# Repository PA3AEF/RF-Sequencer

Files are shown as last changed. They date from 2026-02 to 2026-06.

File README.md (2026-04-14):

# **RF‑Sequencer**

The RF‑Sequencer provides deterministic, safe, and hardware‑independent control of RF transmit and receive path transitions.  
It is designed for radio systems that require strict sequencing, amplifier protection, and predictable relay behavior under all conditions.

The firmware architecture emphasizes clarity, safety, and long‑term maintainability.  
Relay hardware, timing rules, and protection logic are abstracted behind stable interfaces, ensuring consistent operation across diverse station configurations.
Earlier work, such as the concepts published by W1GHZ (Paul Wade) helped establish the fundamental principles of safe RF path control.
This RF‑Sequencer continues that lineage with a modern, firmware‑driven architecture that emphasizes clarity, determinism, and long‑term maintainability.

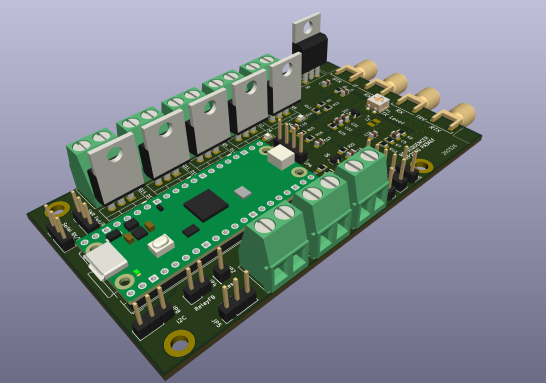
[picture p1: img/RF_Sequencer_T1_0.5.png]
RF Sequencer


## **Key Features**

- Deterministic transmit/receive sequencing  
- Integrated protection engine with SAFE‑mode enforcement  
- High‑speed ADC sampling for forward and reflected power  
- VSWR and fast reflected‑spike protection (REF_FAST)
- Hardware‑independent relay abstraction  
- Support for monostable and latching relays  
- Configurable timing and topology  
- Structured event output for external integration  
- Minimal configuration surface  
- Designed for reliability in demanding RF environments  

## **Why Another Sequencer?**

Existing RF sequencers, including the influential **W1GHZ Mark 5**, proved that microcontroller‑based protection can outperform analog timing chains. But modern stations demand more: deterministic firmware behavior, structured telemetry, remote monitoring, fault latching, and safe operation in unattended or tower‑top installations.

This project was created to provide:

- A **fully deterministic** main‑loop architecture  
- **Sub‑millisecond protection paths** (REF_FAST)  
- A **machine‑readable event stream** for dashboards and automation  
- A **human‑readable logging channel** for operators  
- A **calibration system** that adapts to any coupler  
- A **robust SAFE‑mode model** suitable for remote sites  

In short: it’s a **next‑generation MCU sequencer**, built on the ideas that came before but engineered for today’s RF environments.

## **Documentation**

The documentation is organized into several focused areas:

### **Overview**
High‑level conceptual introduction to the system.  
- `docs/overview/overview.md`

### **Architecture**
Detailed subsystem specifications and internal design.  
- `docs/architecture/firmware-architecture.md`  
- `docs/architecture/relay-architecture.md`

### **Integration**
External systems can interact with the sequencer through a structured event stream.  
Events reflect internal state transitions, protection triggers, relay actions, and measurement updates.   
Guidance for consuming sequencer events and coordinating external systems:
- `docs/integration/event-monitoring-example.md`
- `docs/integration/integration-examples.md`
- `docs/integration/integration-guide.md`

### **Quickstart**
Installation‑specific setup and basic configuration.  
- `docs/quickstart/quickstart.md`

### **Reference (optional)**
Command‑line reference, event definitions, and configuration schema.  
- `docs/reference/`

## **Design Philosophy**

The RF‑Sequencer is built around several core principles:

- **Safety first** — protection logic overrides all other behavior  
- **Determinism** — no asynchronous state changes  
- **Hardware abstraction** — relay details are isolated behind stable interfaces  
- **Minimal configuration** — only essential structural parameters are exposed  
- **Predictability** — timing and transitions follow strict rules  

These principles ensure reliable operation in both simple and complex RF installations.

## **Contributing**

Contributions that improve clarity, safety, or maintainability are welcome.  
Please ensure that changes preserve the architectural principles described in the documentation.

# **License**

This project uses a dual‑license model:

- **Firmware:** binary‑only, see `LICENSE_FIRMWARE.md`
- **Hardware:** CERN OHL‑P, see `LICENSE_HARDWARE.md`

A human‑readable summary is provided in:

- `LICENSE_NOTICE.md`

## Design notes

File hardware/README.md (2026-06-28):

# Hardware

Everything rekated to Hardware.  PCB's (4 layers!) can be easily ordered from JLCPCB. Submit the production ZIP file located in the PCB section. Files are provided for PCBA (PCB Assembly) but it is expensive for small series. Some experience with SMDsoldering is required.

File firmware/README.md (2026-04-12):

# **RF‑Sequencer Firmware**

This folder contains the **precompiled firmware binaries** for the RF‑Sequencer.  
The firmware is distributed as UF2 files and can be flashed directly to the microcontroller without installing any development tools.

If you only want to operate the sequencer, this is the only folder you need.

---

RF_Sequencer
## **Firmware Releases**

Precompiled firmware files are located in: firmware/releases

Each release contains:

- `RFSequencer-PicoTYPE-VX.Y.uf2` — main firmware image  
- `CHANGELOG.md` entry describing what changed  

You can also download firmware from the GitHub Releases page.

---

## **Flashing the Firmware**

The RF‑Sequencer uses a USB mass‑storage bootloader.  
To flash the firmware:

1. Connect the device to your computer via USB.
2. Enter bootloader mode:
   - Press and hold the BOOTSEL button  
   - Plug in the USB cable  
   - Release the button  
3. A new drive will appear (e.g., `RPI-RP2`).
4. Drag‑and‑drop the `.uf2` file onto the drive.
5. The device will reboot automatically.

Detailed instructions are available in: docs/quickstart/firmware-update.md

---

## **Configuration & Operation**

After flashing, connect to the device using any serial terminal:

- **115200 baud**
- **8N1**
- Local echo off

You will see the CLI prompt: >

Documentation for all commands is available in: docs/firmware/cli.md

---

## **Notes**

- Firmware source code is not included in this repository.
- All configuration values are stored in non‑volatile memory.
- You can safely update firmware without losing your settings.

---

If you need help updating or recovering the device, refer to the troubleshooting section:
`docs/troubleshooting/`

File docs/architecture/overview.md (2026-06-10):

---
title: Overview
parent: Architecture
nav_order: 1
---

# Overview

# **RF‑Sequencer Architecture Overview**

The RF‑Sequencer provides a deterministic control layer for managing RF path transitions, amplifier protection, and timing‑critical sequencing in radio systems.  
Its architecture is designed around clarity, predictability, and hardware independence, ensuring consistent behavior across a wide range of station configurations.

This document introduces the major architectural components and explains how they interact at a conceptual level.  
For detailed subsystem specifications, see:

- **Firmware Architecture**  
  `firmware-architecture.md`

- **Relay Subsystem Architecture**  
  `relay-architecture.md`

---

## **System Purpose**

The sequencer coordinates RF transmit and receive transitions while enforcing strict protection rules.  
Its primary goals are:

- ensuring safe amplifier operation  
- preventing hot‑switching of relays  
- providing deterministic timing behavior  
- abstracting hardware differences  
- enabling reliable integration with external systems  

The architecture is intentionally modular, allowing each subsystem to operate independently while contributing to a unified sequencing model.

---

## **Core Architectural Principles**

### **Determinism**
All timing, transitions, and protection responses follow predictable rules.  
No subsystem introduces nondeterministic behavior.

### **Hardware Abstraction**
Relay types, topologies, and station‑specific wiring are abstracted behind stable interfaces.  
The state machine and protection engine operate without knowledge of physical hardware details.

### **Safety First**
Faults, invalid states, and unexpected conditions always collapse into a known‑safe configuration.  
Protection logic is integrated throughout the architecture rather than layered on top.

### **Minimal Configuration Surface**
Only essential structural properties (relay topology, relay type, timing parameters) are configured.  
All other behavior is derived from architecture rules.

---

## **High‑Level Architecture**

The system is composed of several cooperating subsystems:

### **State Machine**
Defines the logical sequencing flow for transmit, receive, and SAFE transitions.  
It is the central coordinator of system behavior.  
See: `firmware-architecture.md`

### **Relay Subsystem**
Abstracts relay topology and actuation model, ensuring deterministic switching independent of hardware.  
See: `relay-architecture.md`

### **Protection Engine**
Monitors RF conditions, timing constraints, and system state to enforce safe operation.  
It can override the state machine to force SAFE transitions.

### **ADC and Measurement Layer**
Provides sampled measurements (e.g., forward/reflected power) used by the protection engine and calibration logic.

### **Event System**
Generates structured events for external systems, enabling integration with logging, GUIs, or automation.

### **Configuration Layer**
Stores structural and timing parameters that define installation‑specific behavior.

### **Main Execution Loop**
Executes the deterministic firmware cycle, evaluating state transitions, protection conditions, and relay actions.

---

## **Interaction Model**

The architecture is built around a clear flow of responsibility:

1. **Measurements** feed into  
2. **Protection logic**, which may override  
3. **State machine transitions**, which drive  
4. **Relay subsystem actions**, which define  
5. **The RF path**, while  
6. **Events** are emitted for external systems.

Each subsystem has a single, well‑defined role, minimizing coupling and simplifying long‑term maintenance.

---

## **Installation Variability**

The sequencer supports a wide range of RF station architectures, including:

- single‑relay TX‑only systems  
- dual‑relay TX+RX systems  
- monostable or latching relays  
- internal or external PA_RDY signaling  
- systems with or without external protection hardware  

These variations are expressed only through configuration and relay topology declarations.  
The architecture itself remains unchanged.

---

## **Design Objectives**

The architecture is designed to:

- provide a stable foundation for long‑term firmware evolution  
- support new relay types and station layouts without redesign  
- ensure predictable behavior under all conditions  
- minimize operator error through clear, deterministic rules  
- maintain separation between logical sequencing and physical hardware  

---

## **Further Reading**

For deeper architectural detail:

- **Firmware Architecture**  
  `firmware-architecture.md`

- **Relay Subsystem Architecture**  
  `relay-architecture.md`

For integration guidance:

- **Integration Examples**  
  `integration-examples.md`

---

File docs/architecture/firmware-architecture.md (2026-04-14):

# **Firmware Architecture**

The firmware architecture defines the deterministic execution model, subsystem boundaries, and interaction rules that govern all sequencing, protection, and relay behavior in the RF‑Sequencer.  
It is designed to provide predictable operation under all conditions while remaining independent of specific relay hardware, station topology, or external integration methods.

This document describes the internal architecture of the firmware.  
For a high‑level conceptual overview, see:

- `overview.md`

For a detailed description of the relay subsystem, see:

- `relay-architecture.md`

---

## **Architectural Goals**

The firmware is built around several core objectives:

- **Deterministic behavior**  
  Every transition, timing step, and protection response follows predictable rules.

- **Hardware abstraction**  
  Relay types, topologies, and electrical characteristics are hidden behind stable interfaces.

- **Safety under all conditions**  
  Faults, invalid states, and unexpected inputs always collapse into a known‑safe configuration.

- **Minimal configuration surface**  
  Only structural and timing parameters are configured; all other behavior is derived.

- **Long‑term maintainability**  
  Subsystems are isolated, with clear responsibilities and minimal coupling.

---

## **Execution Model**

The firmware operates in a deterministic main loop.  
Each cycle evaluates:

- state machine transitions  
- protection conditions  
- relay subsystem actions  
- event generation  
- timing progression  

No asynchronous execution paths modify system state.  
All changes occur within the controlled boundaries of the main loop, ensuring predictability and simplifying reasoning about system behavior.

---

## **State Machine**

The state machine defines the logical sequencing flow for transmit, receive, and SAFE transitions.  
It is the central coordinator of system behavior and the primary consumer of subsystem outputs.

The state machine:

- evaluates input conditions  
- determines the next logical state  
- requests relay transitions  
- coordinates timing windows  
- interacts with the protection engine  

The state machine does **not** interact with hardware directly.  
All physical actions are routed through the relay subsystem and timing model.

For relay subsystem details, see `relay-architecture.md`.

---

## **Relay Subsystem (Summary)**

The relay subsystem abstracts the physical RF switching hardware.  
It models:

- relay topology (single‑relay TX‑only or dual‑relay TX+RX)  
- actuation type (monostable or latching)  
- deterministic transition semantics  

The state machine issues logical relay requests; the subsystem translates them into hardware‑specific actions while guaranteeing:

- ordered transitions  
- bounded switching latency  
- no ambiguous intermediate states  
- consistent SAFE‑mode behavior  

For the full subsystem specification, see `relay-architecture.md`.

---

## **Protection Engine**

The protection engine enforces safe operation by monitoring measurement inputs, timing constraints, and system state.  
It can override the state machine to force SAFE transitions when required.

The protection engine evaluates:

- forward and reflected power  
- timing violations  
- invalid state combinations  
- external PA_RDY conditions  
- calibration validity  

When a protection condition is triggered, the engine:

- forces the system into SAFE mode  
- requests a known‑safe relay configuration  
- emits protection events  
- prevents further transitions until conditions clear  

Protection logic is integrated throughout the architecture rather than layered on top.

---

## **ADC and Measurement Layer**

The ADC subsystem provides sampled measurements used by the protection engine and calibration logic.  
It ensures:

- stable sampling intervals  
- noise‑aware averaging  
- predictable update timing  
- isolation from the main loop’s sequencing logic  

Measurements include:

- forward power  
- reflected power  
- auxiliary analog inputs (installation‑dependent)

The measurement layer does not interpret values; interpretation is handled by the protection engine and calibration subsystem.

---

## **Calibration Layer**

The calibration subsystem converts raw ADC readings into meaningful engineering values.  
It applies:

- scaling factors  
- offsets  
- linearization rules  

Calibration parameters are stored in the configuration layer and validated at startup.  
Invalid calibration data forces SAFE‑mode operation until corrected.

---

## **Event System**

The event system generates structured events that external systems can consume for logging, GUIs, or automation.  
Events are emitted for:

- state transitions  
- protection triggers  
- relay actions  
- configuration changes  
- measurement updates  

Events are strictly informational; they do not influence internal logic.

For integration examples, see `integration-examples.md`.

---

## **Configuration Layer**

The configuration layer stores installation‑specific parameters, including:

- relay topology  
- relay type  
- timing values  
- calibration data  
- protection thresholds  

Configuration is validated at startup.  
Invalid or incomplete configuration forces SAFE‑mode operation.

The configuration layer does not contain operational logic; it only provides structured data to other subsystems.

---

## **Main Execution Loop**

The main loop executes the deterministic firmware cycle:

1. read measurements  
2. evaluate protection conditions  
3. evaluate state machine transitions  
4. compute relay actions  
5. update timing windows  
6. emit events  

No subsystem modifies state outside this loop.  
This ensures predictable timing and simplifies debugging, integration, and long‑term maintenance.

---

## **Subsystem Boundaries**

Each subsystem has a single, well‑defined responsibility:

- **State Machine** — logical sequencing  
- **Relay Subsystem** — hardware abstraction  
- **Protection Engine** — safety enforcement  
- **ADC Layer** — measurement acquisition  
- **Calibration Layer** — measurement interpretation  
- **Event System** — external communication  
- **Configuration Layer** — installation parameters  
- **Main Loop** — deterministic execution  

This separation ensures that changes in one subsystem do not propagate unintended effects into others.

---

## **Design Rationale**

The architecture is intentionally conservative.  
RF systems demand predictable behavior, and the cost of nondeterminism is high.  
By isolating subsystems, enforcing strict sequencing rules, and abstracting hardware differences, the firmware remains stable across:

- new relay types  
- new station architectures  
- new protection requirements  
- future firmware extensions  

The architecture is designed to evolve without compromising safety or determinism.

---

## **Further Reading**

- **Architecture Overview**  
  `overview.md`

- **Relay Subsystem Architecture**  
  `relay-architecture.md`

- **Integration Examples**  
  `integration-examples.md`

---

**File 2 of 4 complete.**  
Say **“next”** and I will deliver **relay-architecture.md**.

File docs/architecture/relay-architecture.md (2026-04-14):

# **Relay Subsystem Architecture**

The relay subsystem provides the abstraction layer between the firmware’s logical sequencing model and the physical RF switching hardware.  
Its purpose is to ensure deterministic, safe, and hardware‑independent relay behavior across all supported station configurations.

This document describes the relay subsystem at an architectural level.  
For the full firmware architecture, see:

- `firmware-architecture.md`

For a high‑level conceptual overview, see:

- `overview.md`

---

## **Purpose and Scope**

The relay subsystem defines how the firmware models, controls, and validates RF switching hardware.  
It isolates the state machine and protection engine from:

- relay topology  
- relay actuation type  
- electrical characteristics  
- timing requirements  
- installation‑specific wiring  

By abstracting these details, the subsystem ensures consistent sequencing behavior regardless of the underlying hardware.

---

## **Topology Model**

The subsystem supports two structural relay configurations:

### **Single‑Relay (TX‑Only)**
A single switching element defines the RF path.  
This topology is used in simple installations where receive path switching is not required.

### **Dual‑Relay (TX+RX)**
Independent transmit and receive paths are controlled by separate relays.  
This topology supports more complex station architectures and provides full control over both RF paths.

Topology is a **structural property** of the installation.  
Once declared, all sequencing and SAFE‑mode behavior is derived automatically.

---

## **Actuation Model**

Relays are modeled using an abstract actuation interface that supports:

- **Monostable relays**  
  Require continuous drive to maintain state.

- **Latching relays**  
  Use pulse‑driven actuation and retain state without continuous power.

The firmware does not expose electrical characteristics to higher layers.  
The state machine interacts only with **logical relay states**, while the subsystem handles the required actuation behavior.

---

## **Deterministic Transition Semantics**

All relay transitions follow strict architectural rules:

- transitions occur in a defined order  
- switching latency is bounded  
- intermediate states are never exposed  
- SAFE‑mode transitions override all other requests  
- relay actions are synchronized with the main execution loop  

These guarantees ensure that the RF path is always in a well‑defined state, even during rapid transitions or fault conditions.

---

## **SAFE‑Mode Behavior**

The relay subsystem integrates tightly with the protection engine.  
When a protection condition is triggered:

- the subsystem forces a known‑safe relay configuration  
- previous relay states are ignored  
- transitions occur deterministically  
- the subsystem remains in SAFE configuration until cleared  

SAFE‑mode behavior is derived from topology and actuation type, ensuring consistent protection across installations.

---

## **Interaction with the State Machine**

The state machine issues **logical relay requests** such as:

- “set TX path active”  
- “set RX path active”  
- “enter SAFE configuration”  

The relay subsystem translates these requests into hardware‑specific actions while enforcing:

- timing constraints  
- topology rules  
- protection overrides  
- deterministic sequencing  

The state machine never interacts with relay hardware directly.

---

## **Interaction with the Protection Engine**

The protection engine may override relay requests at any time.  
When this occurs:

- the subsystem immediately transitions to SAFE configuration  
- pending relay actions are discarded  
- the state machine is informed through protection events  

This ensures that relay behavior always reflects the current safety requirements.

---

## **Configuration Parameters**

The relay subsystem relies on configuration values that define:

- relay topology  
- relay type (monostable or latching)  
- actuation timing  
- SAFE‑mode configuration  

These parameters are validated at startup.  
Invalid configuration forces the system into SAFE mode until corrected.

---

## **Design Objectives**

The relay subsystem is designed to:

- provide a stable abstraction for all relay hardware  
- ensure deterministic switching behavior  
- maintain safety under all conditions  
- minimize configuration complexity  
- support future relay types without architectural changes  

Its design allows the firmware to evolve while preserving predictable RF path control.

---

## **Further Reading**

- **Firmware Architecture**  
  `firmware-architecture.md`

- **Architecture Overview**  
  `overview.md`

- **Integration Examples**  
  `integration-examples.md`

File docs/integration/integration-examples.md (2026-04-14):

# **Integration Examples**

This document describes how external systems can integrate with the RF‑Sequencer using its event‑driven communication model.  
It provides architectural guidance for consuming sequencer events, reacting to state changes, and coordinating external hardware or software systems.

For the full firmware architecture, see:

- `firmware-architecture.md`

For a high‑level overview, see:

- `overview.md`

---

## **Integration Model**

The RF‑Sequencer exposes a structured event stream that external systems can consume to monitor system behavior or coordinate additional actions.  
Events reflect internal state transitions, protection triggers, relay actions, and measurement updates.

Integration is based on three principles:

- **Events are authoritative**  
  External systems should treat sequencer events as the source of truth for system state.

- **Events are informational**  
  They do not influence internal logic; the sequencer never depends on external acknowledgments.

- **Events are stable**  
  The event format is designed to remain consistent across firmware versions.

---

## **Event Categories**

External systems can expect events in several categories:

### **State Events**
Indicate transitions between logical states such as transmit, receive, and SAFE.  
These events allow external systems to synchronize with the sequencer’s operational mode.

### **Protection Events**
Report protection triggers, threshold violations, and SAFE‑mode enforcement.  
These events are essential for logging, diagnostics, and external safety interlocks.

### **Relay Events**
Reflect changes in relay configuration or topology‑dependent switching actions.  
They allow external systems to track RF path changes without interpreting internal logic.

### **Measurement Events**
Provide calibrated measurement updates such as forward and reflected power.  
These events support GUIs, logging systems, and monitoring dashboards.

### **Configuration Events**
Indicate changes to installation parameters or calibration data.  
External systems can use these events to update their internal models.

---

## **Integration Patterns**

External systems typically integrate with the sequencer using one of the following patterns:

### **Monitoring**
A passive system consumes events to display status, log activity, or provide operator feedback.  
This pattern requires no control over the sequencer.

### **Supervisory Control**
A supervisory system reacts to sequencer events by coordinating external hardware such as amplifiers, filters, or antenna switches.  
The sequencer remains the authoritative controller of RF path transitions.

### **Automation**
Automation systems use sequencer events to trigger workflows, scripts, or station‑level logic.  
This pattern is common in remote or unattended installations.

---

## **Event Consumption Guidelines**

External systems should follow these architectural guidelines:

- **Do not infer state from timing or relay behavior**  
  Always rely on explicit state events.

- **Do not attempt to override protection behavior**  
  SAFE‑mode transitions are mandatory and cannot be bypassed.

- **Do not assume relay topology**  
  Relay events reflect the configured topology; external systems should not hard‑code assumptions.

- **Do not depend on event ordering beyond architectural guarantees**  
  Events reflect internal sequencing but should not be used to infer timing windows.

- **Do not attempt to synchronize with internal timing**  
  The sequencer’s timing model is internal and deterministic; external systems should react only to events.

---

## **Integration Responsibilities**

External systems are responsible for:

- interpreting event data  
- maintaining their own internal state models  
- coordinating external hardware based on sequencer output  
- handling communication errors or disconnections  
- ensuring that their behavior does not conflict with sequencer safety rules  

The sequencer does not validate or supervise external system behavior.

---

## **Design Intent**

The integration model is intentionally simple.  
By exposing a stable event stream and avoiding bidirectional control dependencies, the sequencer remains:

- predictable  
- safe  
- easy to integrate  
- resilient to external failures  

This design ensures that the sequencer can operate reliably in diverse environments without requiring complex coordination logic.

---

## **Further Reading**

- **Architecture Overview**  
  `overview.md`

- **Firmware Architecture**  
  `firmware-architecture.md`

- **Relay Subsystem Architecture**  
  `relay-architecture.md`

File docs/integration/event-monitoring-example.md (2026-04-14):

# **Event Monitoring Examples**

The examples here demonstrate how an external system can consume the RF‑Sequencer’s event stream using a simple HTML page. or Python script. It illustrates the structure of emitted events and shows how they can be displayed or processed by a monitoring application.

For architectural integration guidance, see:

- `integration-examples.md`  
- `firmware-architecture.md`  
- `overview.md`

---

## **Purpose**

The purpose of this example is to:

- show the structure of sequencer events  
- demonstrate how an external system can receive and display them  
- provide a minimal reference implementation for developers  

This example does **not** define any sequencing logic, protection behavior, or timing rules.  
It is purely an illustration of event consumption.

---

## **Event Format**

Events are emitted as structured JSON objects.  
Each event contains:

- a **type** identifying the event category  
- a **timestamp**  
- a **payload** containing event‑specific data  

Example event:

```json
{
  "type": "state",
  "timestamp": "2025-01-01T12:00:00.000Z",
  "payload": {
    "from": "receive",
    "to": "transmit"
  }
}
```

Other event types follow the same structure:

- `state`  
- `protection`  
- `relay`  
- `measurement`  
- `configuration`

---

## **Minimal HTML Event Monitor**

The following HTML example connects to the sequencer, receives events, and displays them in a simple log window.  
It is intentionally minimal and suitable as a starting point for GUIs, dashboards, or automation tools.

```html
<!DOCTYPE html>
<html>
<head>
  <meta charset="utf-8">
  <title>RF‑Sequencer Event Monitor</title>
  <style>
    body { font-family: sans-serif; background: #111; color: #eee; }
    #log { white-space: pre; font-family: monospace; padding: 1rem; }
  </style>
</head>
<body>

<h2>RF‑Sequencer Event Monitor</h2>
<button id="connect">Connect</button>

<script>
  const log = msg => {
    document.getElementById('log').textContent += msg + "\n";
  };

  document.getElementById('connect').onclick = async () => {
    try {
      const port = await navigator.serial.requestPort();
      await port.open({ baudRate: 115200 });

      const reader = port.readable.getReader();
      log("Connected to RF‑Sequencer");

      while (true) {
        const { value, done } = await reader.read();
        if (done) break;

        const text = new TextDecoder().decode(value);
        text.trim().split("\n").forEach(line => {
          try {
            const event = JSON.parse(line);
            log(JSON.stringify(event, null, 2));
          } catch {
            log("Invalid JSON: " + line);
          }
        });
      }
    } catch (err) {
      log("Connection error: " + err);
    }
  };
</script>

</body>
</html>
```

This example:

- connects to the sequencer  
- reads the event stream  
- parses each line as JSON  
- displays events in a readable format  

It does not implement buffering, reconnection, or filtering.  
Those concerns are left to the integrating system.

---

# **Python Event Monitor**

This example demonstrates how a Python application can consume the RF‑Sequencer’s event stream over a serial connection.  
It illustrates how to read line‑delimited JSON events, parse them, and process them in a deterministic loop.

For architectural integration guidance, see:

- `integration-examples.md`  
- `event-monitoring-example.md`  
- `firmware-architecture.md`

---

## **Purpose**

The purpose of this example is to:

- show how to read the sequencer’s event stream  
- parse structured JSON events  
- provide a minimal reference for Python‑based monitoring systems  

This example does **not** implement buffering, reconnection, or GUI logic.  
It is intentionally minimal and suitable as a foundation for logging, dashboards, or automation tools.

---

## **Python Example**

```python
import json
import serial

def log(msg):
    print(msg)

def main():
    # Adjust the serial port to match your system
    port = serial.Serial('/dev/ttyUSB0', 115200, timeout=1)
    log("Connected to RF‑Sequencer")

    buffer = ""

    while True:
        data = port.read(128).decode(errors='ignore')
        if not data:
            continue

        buffer += data

        # Process complete lines
        while "\n" in buffer:
            line, buffer = buffer.split("\n", 1)
            line = line.strip()
            if not line:
                continue

            try:
                event = json.loads(line)
                log(json.dumps(event, indent=2))
            except json.JSONDecodeError:
                log(f"Invalid JSON: {line}")

if __name__ == "__main__":
    main()
```

---

## **Integration Notes**

- The sequencer emits one JSON event per line.  
- Events are self‑contained and do not require correlation.  
- External systems should not infer timing or sequencing from event order.  
- Protection events should be logged and acted upon immediately.  
- Relay events reflect the configured topology and should not be interpreted as timing signals.  

---

## **Further Reading**

- **Integration Guide**  
  `integration-examples.md`

- **Firmware Architecture**  
  `firmware-architecture.md`

- **Relay Subsystem Architecture**  
  `relay-architecture.md`

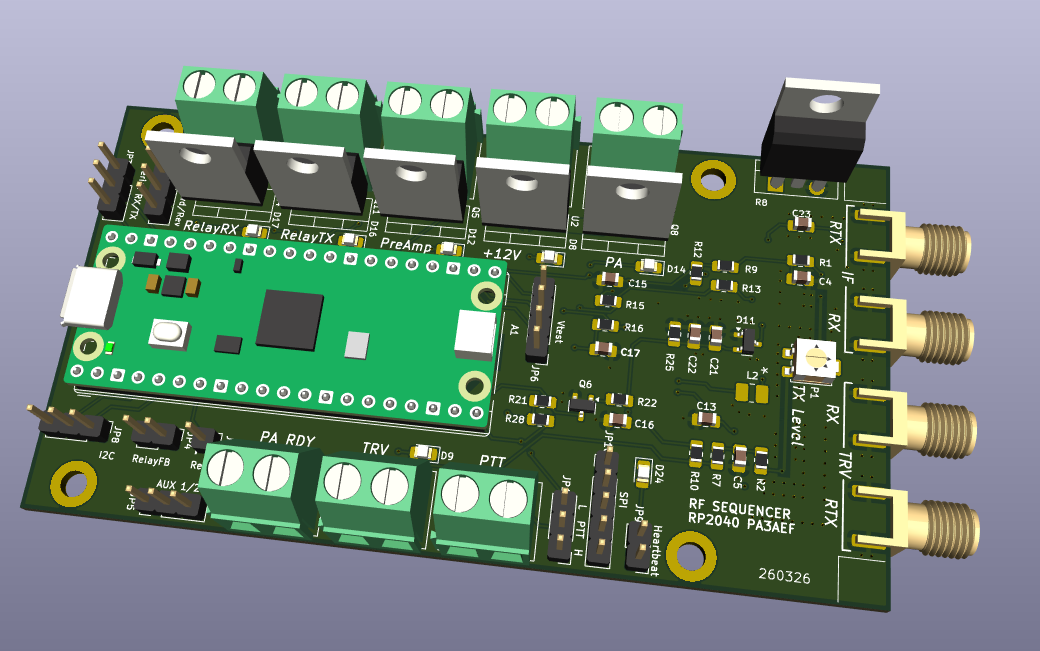
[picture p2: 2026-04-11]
hardware/RF_Sequencer_T2.png

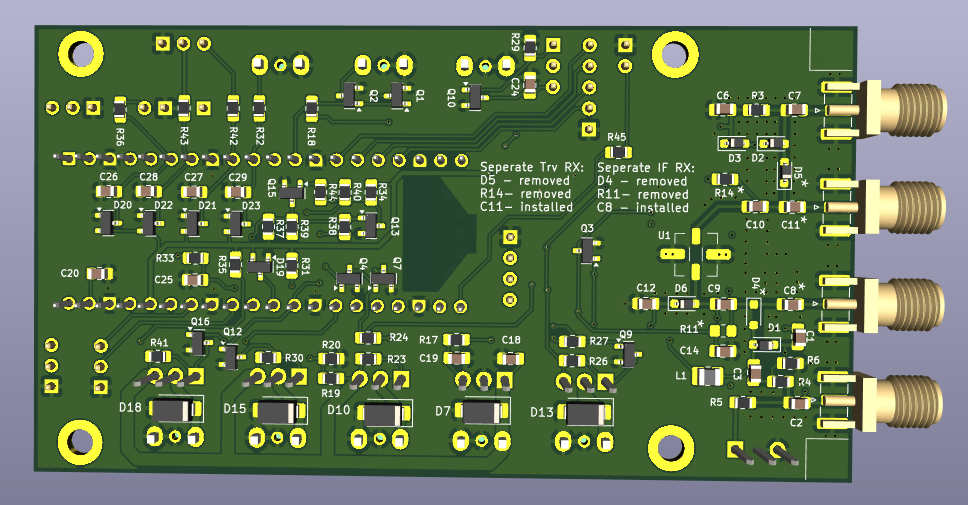
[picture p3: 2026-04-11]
hardware/RF_Sequencer_B1.png

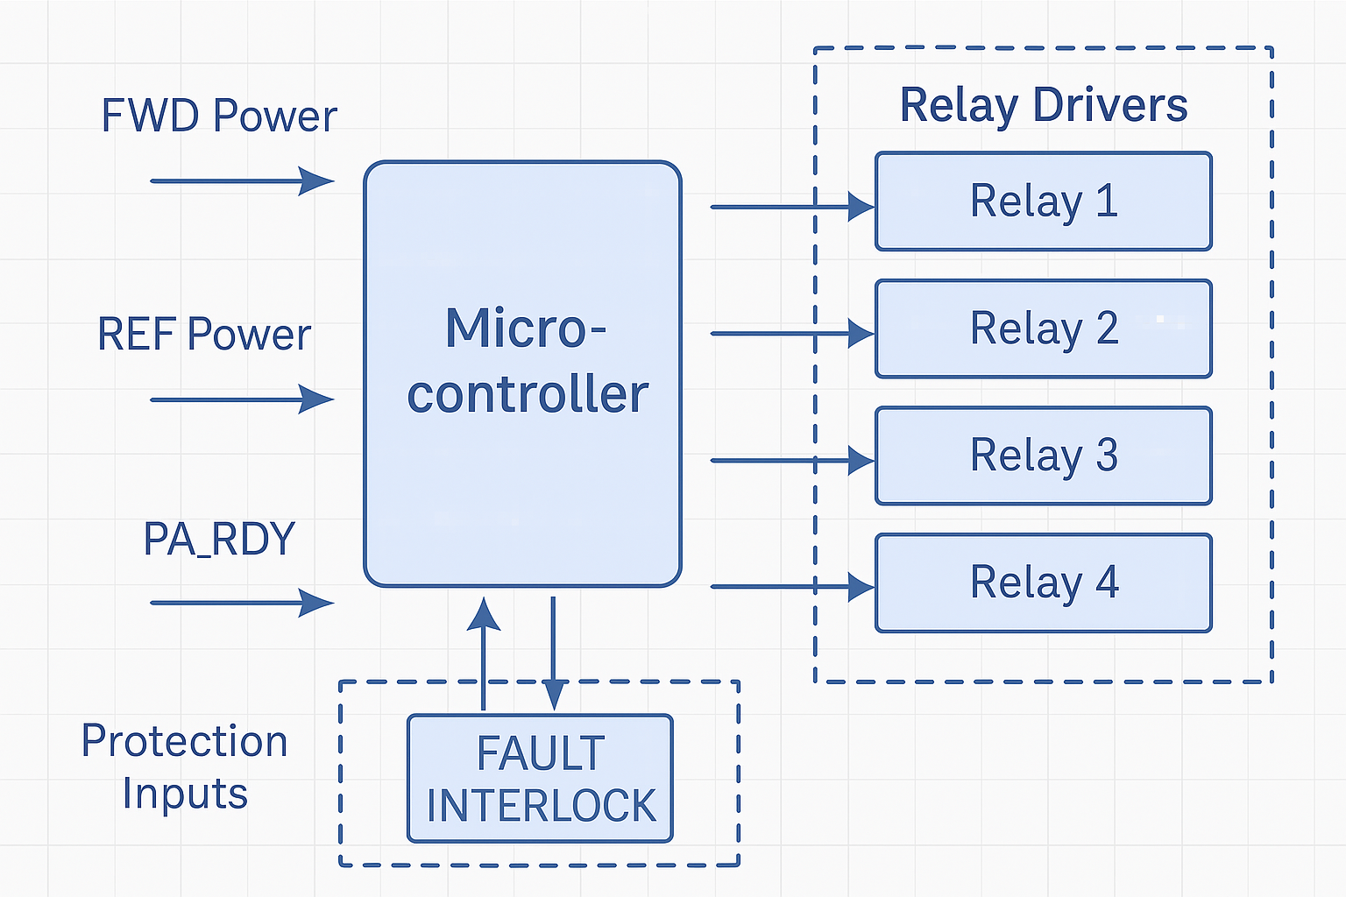
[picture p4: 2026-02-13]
img/hw-philosophy.png

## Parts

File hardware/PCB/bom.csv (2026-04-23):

Designator | Footprint | Quantity | Value | LCSC Part #
A1 | RaspberryPi_Pico_Common_THT | 1 | RaspberryPi_Pico
C1, C10, C11, C12, C13, C14, C15, C16, C2, C21, C24, C25, C26, C27, C28, C29, C3, C4, C5, C6, C7, C8, C9 | 0805 | 23 | 1nF
C17, C19, C20 | 0805 | 3 | 100nF
C18 | 0805 | 1 | 330nF
C22 | 0805 | 1 | 22uF
C23 | 0805 | 1 | 2.2pF
D1, D2, D5, D6 | D_SOD-323_HandSoldering | 4 | BAR63
D10, D13, D15, D18, D7 | D_SMA | 5 | 1N4001 | C2456
D11, D19, D20, D21, D22, D23 | SOT-23 | 6 | BAT54S | C8592
D12, D17 | 0805 | 2 | LED White
D14 | 0805 | 1 | LED Yellow
D16 | 0805 | 1 | LED Green
D24 | 0805 | 1 | Red
D29, D30 | D_SOD-323_HandSoldering | 2 | BAV16W
D3 | D_SOD-323_HandSoldering | 1 | BAR64
D8 | 0805 | 1 | LED Blue
D9 | 0805 | 1 | LED Red
J1, J2, J3, J4 | SMA_Samtec_SMA-J-P-H-ST-EM1_EdgeMount | 4 | SMA
J10, J11, J12, J5, J6, J7, J8, J9 | Screw terminal 3 pin | 8 | Screw_Terminal
JP1, JP3, JP5, JP7, JP8 | PinHeader_1x03_P2.54mm_Vertical | 5 | Conn_01x03
JP10 | PinHeader_1x05_P2.54mm_Vertical | 1 | Conn_01x05
JP2 | PinHeader_1x01_P2.54mm_Vertical | 1 | Conn_01x01
JP4, JP9 | PinHeader_1x02_P2.54mm_Vertical | 2 | Conn_01x02
JP6 | PinHeader_1x04_P2.54mm_Vertical | 1 | Conn_01x04
L1 | 1008 | 1 | 1uH
P1 | Potentiometer_Bourns_3314G_Vertical | 1 | 1K | C780221
Q1, Q10, Q12, Q16, Q2, Q3, Q4, Q7, Q9 | SOT-23 | 9 | MMBF170 | C130879
Q11, Q14, Q5, Q8 | TO-220-3_Vertical | 4 | IRF9Z24S | C2576
Q13, Q15, Q6 | SOT-23 | 3 | MMBTA13 | C8520
R1, R2 | 0805 | 2 | 68
R10, R13, R14 | 0805 | 3 | 560
R12, R9 | 0805 | 2 | 330
R15, R20, R32, R34, R37, R38, R44 | 0805 | 7 | 10K
R16 | 0805 | 1 | 5K6
R17, R18, R21, R27, R28, R31, R35, R45 | 0805 | 8 | 3K3
R19, R22 | 0805 | 2 | 56K
R23, R26, R30, R41 | 0805 | 4 | 6K8
R24 | 0805 | 1 | 20K
R25 | 0805 | 1 | 47K
R29, R39, R40 | 0805 | 3 | 100K
R3 | 0805 | 1 | 300
R33, R36, R42, R43 | 0805 | 4 | 1K
R4 | 0805 | 1 | 39
R5 | 0805 | 1 | 100
R6 | 0805 | 1 | 150
R7 | 0805 | 1 | 120
R8 | TO-220-2_Vertical Resistor | 1 | VPR220 50
U1 | MSA_1 | 1 | MAR-6
U2 | TO-220-3_Vertical | 1 | LM7805_TO220

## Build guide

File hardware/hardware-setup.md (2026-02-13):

# **Hardware Setup, Wiring Basics, and First‑Time Preparation**

## **1. Introduction**

The RF‑Sequencer is a modern, safety‑focused, and configurable RF transmit/receive sequencer designed to protect radios, amplifiers, relays, and other station hardware. It is built around the Raspberry Pi Pico/Pico2 platform, chosen for reliability, speed, and ease of firmware management. [\[github.com\]](https://github.com/PA3AEF/RF-Sequencer)

This document guides you through essential hardware wiring, preparation, and the first power‑up process.

***

## **2. Required Components**

*   RF‑Sequencer PCB
*   Raspberry Pi Pico or Pico2 (recommended due to better performance and lower power consumption) [\[github.com\]](https://github.com/PA3AEF/RF-Sequencer)
*   Power supply (5 V USB for the Pico; 12–13.8 V system supply for station devices)
*   TX, RX, PA‑enable lines (depending on station hardware)
*   TR relay
*   Cables for digital inputs (PTT, RFSENSE, PA\_RDY, RELAY\_FB, AUX inputs)
*   Coaxial cabling for RF path (radio ↔ sequencer ↔ amplifier/preamp)
*   A dummy load or antenna *connected before any RF test*

***

## **3. Understanding the Sequencer I/O**

The sequencer monitors and controls:

### **Digital Inputs**

*   **PTT** – primary keying line from your radio.
*   **RFSENSE** – RF‑power‑based keying.
*   **PA\_RDY** – signals power amplifier readiness.
*   **RELAY\_FB** – feedback from TR relay verifying mechanical movement.
*   **AUX1–AUX3** – general‑purpose logic inputs.  
    Digital inputs are *debounced and normalized* internally to ensure stable operation. [\[github.com\]](https://github.com/PA3AEF/RF-Sequencer)

### **Analog Inputs**

*   **Forward Power ADC**
*   **Reflected Power ADC**
*   **Test ADC**

The sequencer derives **VSWR**, detects **fast reflected power spikes**, and evaluates system health continuously. [\[github.com\]](https://github.com/PA3AEF/RF-Sequencer)

### **Outputs**

All outputs (TX, RX, PA\_ENABLE, TR relay, indicator LEDs) are controlled exclusively by the sequencer’s internal state machine. [\[github.com\]](https://github.com/PA3AEF/RF-Sequencer)

***

## **4. Wiring Basics**

### **4.1 Connect Power**

*   Power the Pico via USB (5 V).
*   Power RF devices (PA, relays) from their appropriate supply rails (commonly 12–28 V depending on hardware).

### **4.2 Connect Control Lines**

*   **PTT from radio → PTT input**
*   **TR relay → TR output**
*   **PA control → PA\_ENABLE output**
*   **RX/TX interlock lines → RX\_ENABLE / TX\_ENABLE outputs**

Ensure **common grounds** between the sequencer, radio, PA, and relay systems.

### **4.3 Connect Feedback Lines**

*   **Relay feedback (RELAY\_FB)** is essential for safety — the sequencer *verifies* the relay moved to the commanded position before enabling RF.
*   **PA\_RDY** wiring ensures the PA must signal readiness before transmit is allowed.

These mechanisms directly support Safe Mode activation if something goes wrong. [\[github.com\]](https://github.com/PA3AEF/RF-Sequencer)

***

## **5. First‑Time Preparation Checklist**

1.  Inspect all wiring for:
    *   correct polarity
    *   clean grounds
    *   no shorts
    *   proper connector seating

2.  Verify control cables BEFORE connecting RF power.

3.  Connect a dummy load or antenna.

4.  With the PA powered but unkeyed:
    *   ensure **PA\_RDY is correct**
    *   ensure relay feedback works (TR relay clicks reliably)

5.  Connect the Pico’s USB to your computer.
    *   The Pico exposes USB for power and firmware handling.
    *   If the bootloader is ever corrupted, it can be easily restored by copying a UF2 file onto the Pico’s USB mass‑storage device. [\[github.com\]](https://github.com/PA3AEF/RF-Sequencer)

***

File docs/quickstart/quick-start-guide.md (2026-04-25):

# **RF‑Sequencer – Quick Start Guide**

This guide helps you get the RF‑Sequencer wired, configured, and operational in just a few minutes.  
It assumes basic familiarity with radios, PTT control, and RF hardware.

---

## **1. Overview**

The RF‑Sequencer ensures safe and deterministic switching between **RX** and **TX** in RF systems.  
It protects your PA, relays, and front‑end by enforcing correct timing and monitoring critical signals:

- PTT  
- PA_RDY  
- Relay feedback  
- VSWR / Reflected power  
- RF‑sense  
- Auxiliary inputs  

The sequencer drives **TX_ENABLE**, **RX_ENABLE**, **PA_ENABLE**, and dual‑coil relays (TX and RX coils).

---

## **2. Hardware Connections**

### **Required connections**
| Signal | Direction | Description |
|---|---|---|
| **PTT_N** | Input | Active‑low PTT from radio or footswitch |
| **PA_RDY** | Input | PA ready / interlock input |
| **RELAY_FB** | Input | Relay position feedback (optional) |
| **FWD / REF ADC** | Input | Coupler forward/reflected power |
| **TX_RELAY** | Output | TX coil drive (monostable or latching) |
| **RX_RELAY** | Output | RX coil drive |
| **TX_ENABLE** | Output | Enables TX path |
| **RX_ENABLE** | Output | Enables RX path |
| **PA_ENABLE** | Output | Enables PA |

### **Relay wiring**
The firmware always supports **two coils**:

- Connect **TX coil** → `PIN_TX_RELAY`
- Connect **RX coil** → `PIN_RX_RELAY`  
- If you use a TX‑only relay, simply leave RX unconnected.

Overlap protection remains active but harmless if RX is not wired.

---

## **3. Power‑Up Behavior**

On boot:

1. Sequencer initializes all GPIOs  
2. Relay outputs default to **RX**  
3. PA is disabled  
4. Faults are cleared  
5. Status is printed over USB (if logging enabled)

---

## **4. USB CLI**

Open a serial terminal at:

```
115200 baud, 8N1
```

You’ll see:

```
RF Sequencer - PA3AEF <build>
> 
```

### **Useful commands**

```
> HELP
> STATUS
> RESET
> GET CONFIG
> SET STATE_DELAY <ms>
> SET ACTUATION MONOSTABLE|LATCHING
> SET INPUT <NAME> ON|OFF
> SET VSWR_LIMIT <float>
> SET REF_FAST_LIMIT <int>
> SET LOGGING ON|OFF
> SET EVENTS ON|OFF
```
Commands are not case senssitive. 
Use **TAB / arrow keys** for command history.

---

## **5. Basic Configuration**

### **Check current settings**
```
> GET CONFIG
```

### **Enable/disable inputs**
```
> SET INPUT PTT ON
> SET INPUT PA_RDY ON
> SET INPUT RELAY_FB ON
> SET INPUT VSWR ON
> SET INPUT REF ON
```

### **Set relay actuation**
```
> SET ACTUATION MONOSTABLE
```
or
```
> SET ACTUATION LATCHING
```

### **Set timing**
```
> SET STATE_DELAY 0        (normal operation)
> SET STATE_DELAY 200      (slow transitions for debugging or slow hardware)
> SET RELAY_TIMEOUT 50
> SET PA_TIMEOUT 200
```

---

## **6. Operating the Sequencer**

### **RX → TX transition**
Triggered by:

- PTT pressed  
- RF‑sense (if enabled)  
- External AUX input (if configured)

Sequence:

1. Disable RX path  
2. Switch relay to TX  
3. Wait for relay feedback (if enabled)  
4. Enable TX path  
5. Enable PA  
6. Monitor VSWR / REF_FAST continuously  

### **TX → RX transition**
Triggered by:

- PTT released  
- Fault condition  
- PA_RDY lost  
- VSWR/REF protection  

Sequence:

1. Disable PA  
2. Disable TX path  
3. Switch relay to RX  
4. Enable RX path  

---

## **7. Protection System**

The sequencer continuously monitors:

- **VSWR**  
- **Fast reflected power**  
- **Relay overlap**  
- **Relay feedback mismatch**  
- **PA_RDY timeout**  
- **Relay timeout**  

On fault:

- PA is disabled  
- TX is disabled  
- Relay returns to RX  
- Fault is latched  
- SAFE MODE is entered  
- Event is logged and emitted over serial  

Clear faults with:

```
> RESET
```

---

## **8. VSWR Calibration**

Start guided VSWR calibration:

```
CALIBRATE
```

Follow on‑screen instructions.

---

## **9. Debugging Tools**

### **State transition delay**
Slows down the sequencer so you can visually observe relay and LED behavior.

```
> SET STATE_DELAY 200
```

Set to zero for normal operation:

```
> SET STATE_DELAY 0
```

### **Event stream**
Machine‑readable events over Serial1:

```
> SET EVENTS ON
```

### **USB logging**
Human‑readable logs:

```
> SET LOGGING ON
```

---

## **10. Firmware Updates**
Firmeare can be downloaded from the firmware section. Follow its instructions to update. 
1. Flash via USB or SWD   
2. Config is preserved across updates  
3. Factory reset if needed:

```
> FACTORY_RESET
```

---

## **11. Safety Notes**

- Always verify relay wiring before connecting RF power  
- Use relay feedback if available  
- Ensure PA_RDY is correctly wired for your amplifier  
- Never bypass VSWR protection unless testing at low power  

---

## **12. Support & Documentation**

- GitHub: `https://github.com/PA3AEF/RF-Sequencer`
- Issues: use GitHub issue tracker  
- Hardware schematics: `/hardware`  
- Firmware docs: `/docs`  

---

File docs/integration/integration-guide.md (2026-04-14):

# **Developer Integration Guide**

This guide describes how external systems can integrate with the RF‑Sequencer using its event‑driven communication model.  
It focuses on architectural concepts rather than implementation details, ensuring that integrations remain stable across firmware versions.

For architectural background, see:

- `docs/architecture/firmware-architecture.md`  
- `docs/overview/overview.md`

---

## **Integration Philosophy**

The sequencer exposes a **unidirectional event stream** that external systems can consume to:

- monitor system state  
- coordinate external hardware  
- trigger automation workflows  
- log protection events  
- display real‑time status  

External systems do **not** control the sequencer’s internal logic.  
The sequencer remains the authoritative controller of RF path transitions and protection behavior.

---

## **Event Model**

Events are structured messages representing internal state changes.  
They fall into several categories:

- **State events** — transmit, receive, SAFE transitions  
- **Protection events** — threshold violations, enforced SAFE‑mode  
- **Relay events** — relay configuration changes  
- **Measurement events** — calibrated forward/reflected power  
- **Configuration events** — updates to installation parameters  

Events are:

- **authoritative** — they reflect the sequencer’s actual state  
- **informational** — they do not require acknowledgment  
- **stable** — the format is designed for long‑term compatibility  

---

## **Integration Patterns**

### **Monitoring Systems**
Consume events to display status, log activity, or provide operator feedback.  
No control over the sequencer is required.

### **Supervisory Controllers**
React to sequencer events to coordinate external hardware such as:

- amplifiers  
- filters  
- antenna switches  
- external protection devices  

The sequencer remains the primary controller of RF path transitions.

### **Automation Systems**
Use events to trigger workflows or scripts, enabling:

- remote operation  
- unattended station control  
- automated protection responses  
- scheduled transmit/receive cycles  

---

## **Architectural Guidelines for Developers**

- **Do not infer state from timing or relay behavior**  
  Always rely on explicit state events.

- **Do not attempt to override protection behavior**  
  SAFE‑mode transitions are mandatory.

- **Do not assume relay topology**  
  Relay events reflect the configured installation.

- **Do not synchronize with internal timing**  
  The sequencer’s timing model is internal and deterministic.

- **Do not depend on event ordering beyond architectural guarantees**  
  Events reflect internal sequencing but should not be used to infer timing windows.

- **Do not attempt to control internal logic**  
  External systems should react to events, not drive state.

---

## **Integration Responsibilities**

External systems are responsible for:

- interpreting event data  
- maintaining their own internal state models  
- coordinating external hardware based on sequencer output  
- handling communication errors or disconnections  
- ensuring their behavior does not conflict with sequencer safety rules  

The sequencer does not validate or supervise external system behavior.

---

## **Design Intent**

The integration model is intentionally simple and robust.  
By exposing a stable event stream and avoiding bidirectional control dependencies, the sequencer remains:

- predictable  
- safe  
- easy to integrate  
- resilient to external failures  

This design ensures reliable operation in diverse environments, from simple home stations to complex automated installations.

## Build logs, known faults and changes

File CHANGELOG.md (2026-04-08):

# Changelog

## v1.4.0 — 2026‑04‑08

### Added
- New relay configuration model:
  - SET RELAY_MODE <NORMAL|LATCHED>
  - SET HAS_RX_RELAY <ON|OFF>
- Persistent config fields:
  - relayMode
  - hasRXRelay
- Status output now includes:
  - RX Relay Present
  - human‑readable Relay Mode
- Boot banner now reports:
  - relay hardware type (TX‑only / TX+RX)
  - current relay mode

### Changed
- Simplified relay mode handling:
  - internal TX‑only / TX+RX modes are derived from HAS_RX_RELAY
  - invalid TX+RX modes on TX‑only hardware are automatically mapped to TX‑only equivalents

### Notes
- Existing configurations default to HAS_RX_RELAY=ON unless overridden.

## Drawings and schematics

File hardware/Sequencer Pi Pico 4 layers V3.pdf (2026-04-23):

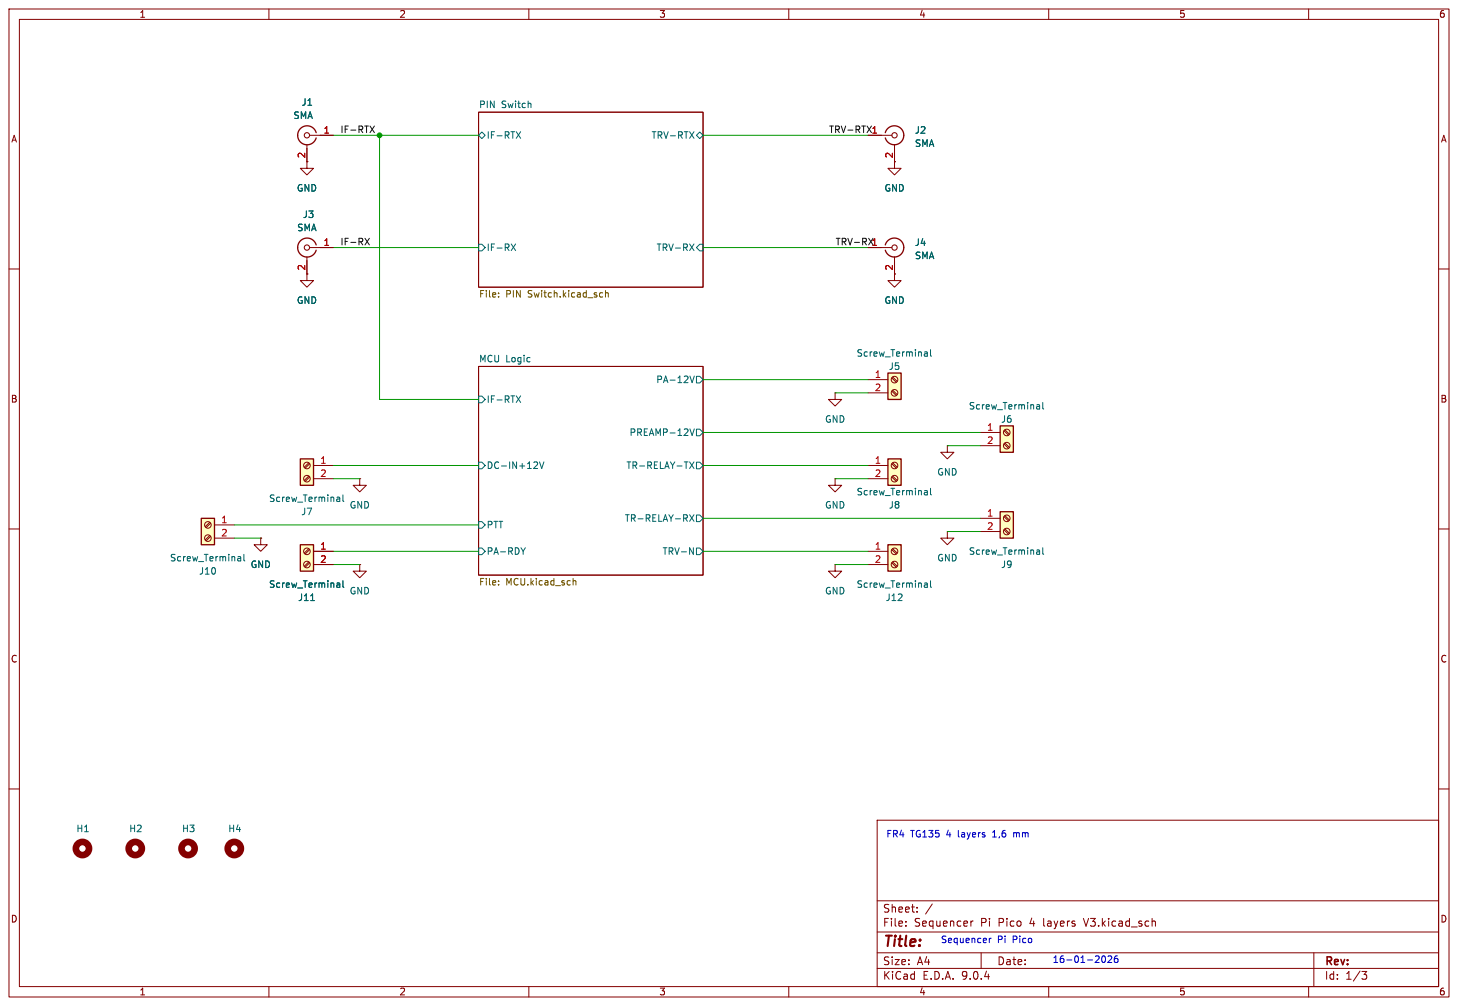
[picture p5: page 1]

PIN Switch File: PIN Switch.kicad_sch DC-IN+12V

2 GND GND GND GND

J8 Screw_Terminal GND GND GND GND

TR-RELAY-RX MCU Logic File: MCU.kicad_sch

16-01-2026 Sequencer Pi Pico FR4 TG135 4 layers 1,6 mm

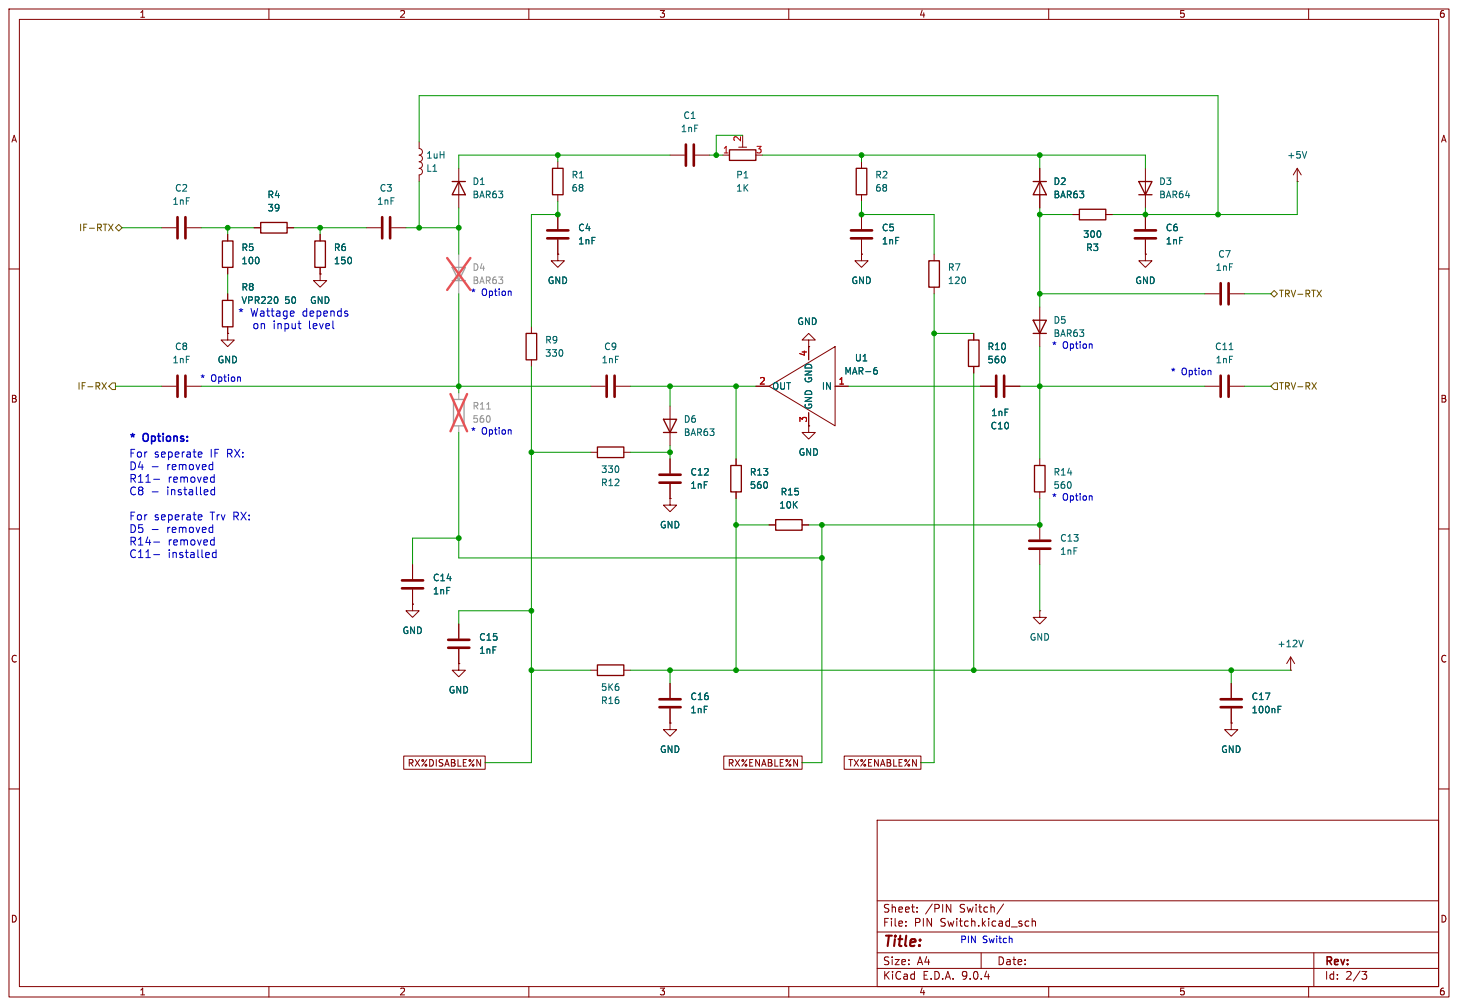
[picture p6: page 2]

100nF GND GND GND GND

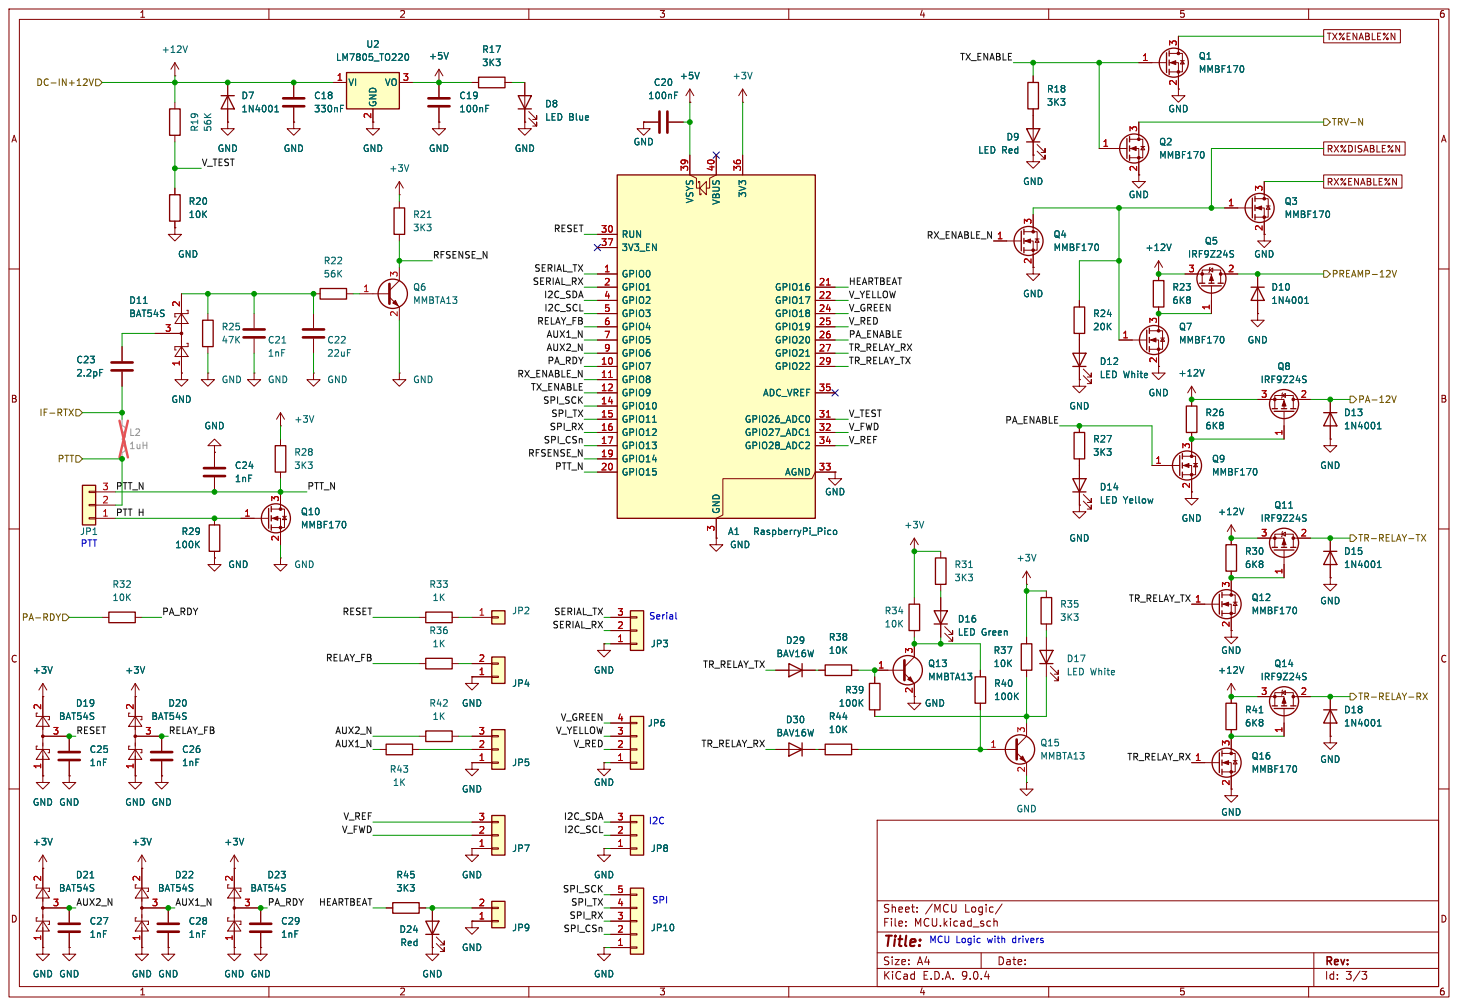
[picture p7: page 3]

2 VO 3 +5V GND GND GND

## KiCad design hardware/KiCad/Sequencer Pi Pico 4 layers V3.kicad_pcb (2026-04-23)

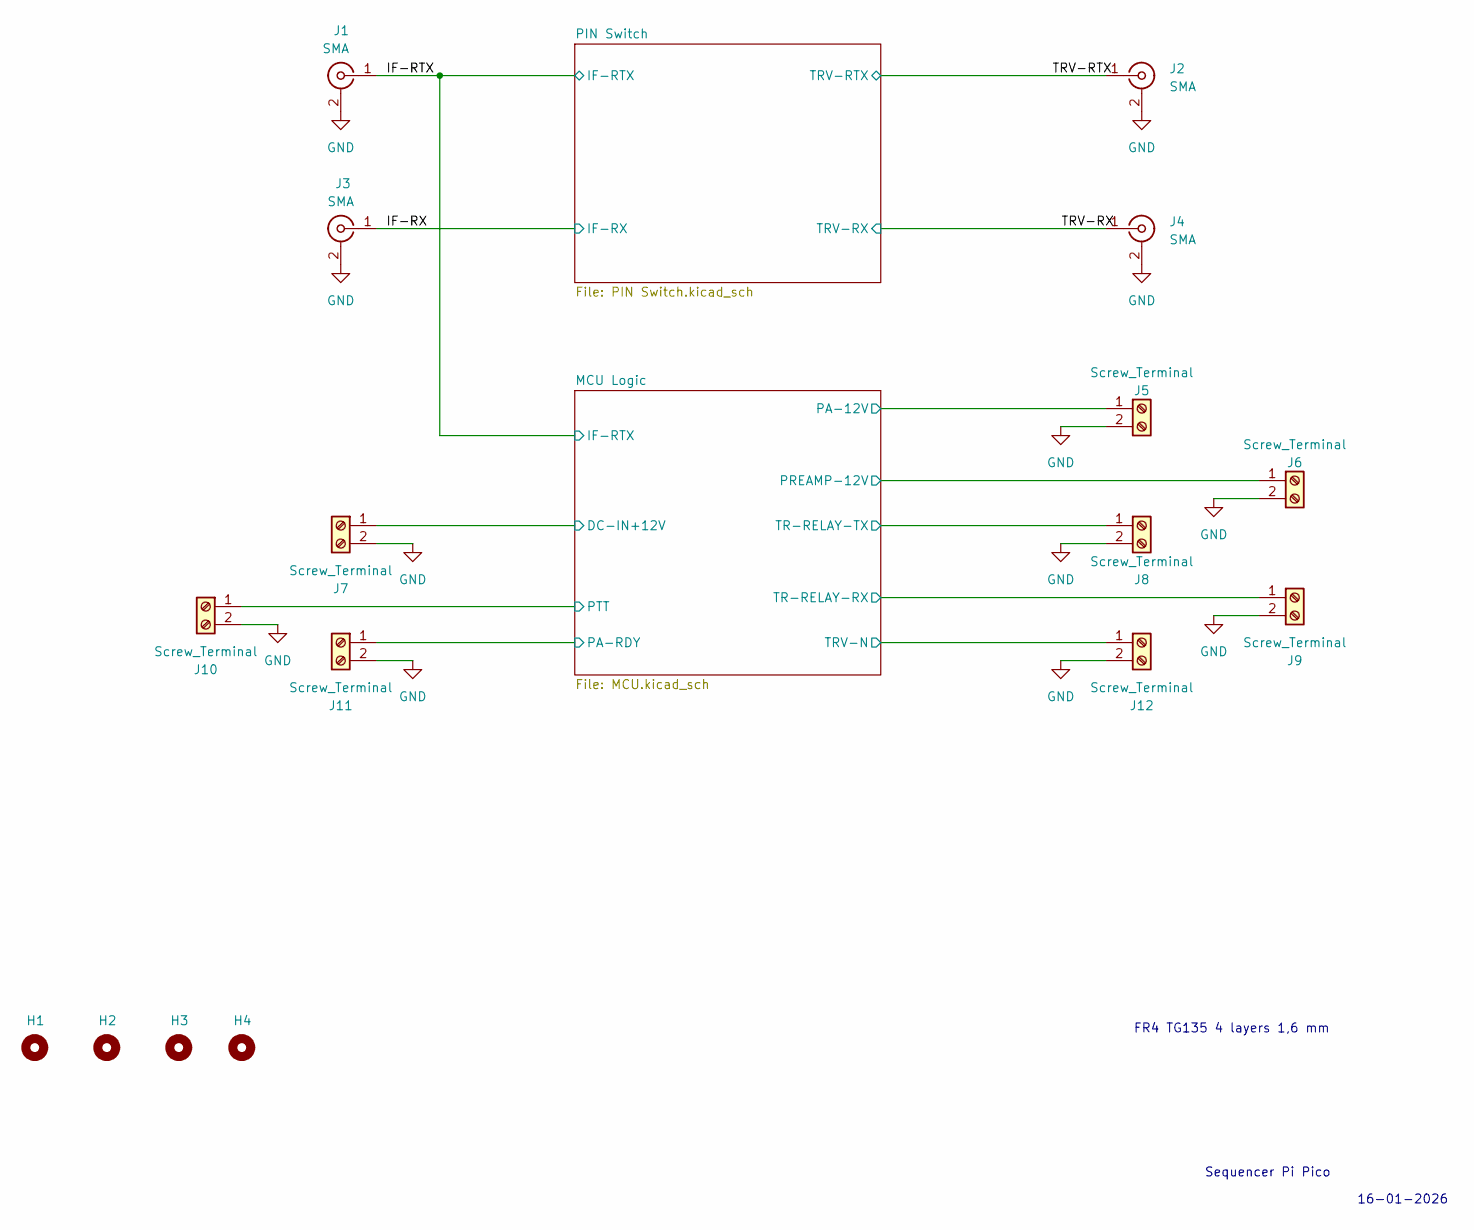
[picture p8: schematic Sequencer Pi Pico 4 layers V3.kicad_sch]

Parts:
H1, H2, H3, H4: MountingHole; MountingHole_3.2mm_M3_DIN965_Pad
J1, J2, J3, J4: SMA; SMA_Samtec_SMA-J-P-H-ST-EM1_EdgeMount
J5, J6, J7, J8, J9, J10, J11, J12: Screw_Terminal; Screw terminal 3 pin

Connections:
+12V: J7.1; also elsewhere on the board
/IF-RTX: J1.1 (In); also elsewhere on the board
/IF-RX: J3.1 (In); also elsewhere on the board
/MCU Logic/PA-12V: J5.1; also elsewhere on the board
/MCU Logic/PA-RDY: J11.1; also elsewhere on the board
/MCU Logic/PREAMP-12V: J6.1; also elsewhere on the board
/MCU Logic/PTT: J10.1; also elsewhere on the board
/MCU Logic/TR-RELAY-RX: J9.1; also elsewhere on the board
/MCU Logic/TR-RELAY-TX: J8.1; also elsewhere on the board
/MCU Logic/TRV-N: J12.1; also elsewhere on the board
/TRV-RTX: J2.1 (In); also elsewhere on the board
/TRV-RX: J4.1 (In); also elsewhere on the board
GND: J1.2 (Ext), J2.2 (Ext), J3.2 (Ext), J4.2 (Ext), J5.2, J6.2, J7.2, J8.2, J9.2, J10.2, J11.2, J12.2; also elsewhere on the board

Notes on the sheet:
16-01-2026
FR4 TG135 4 layers 1,6 mm
Sequencer Pi Pico

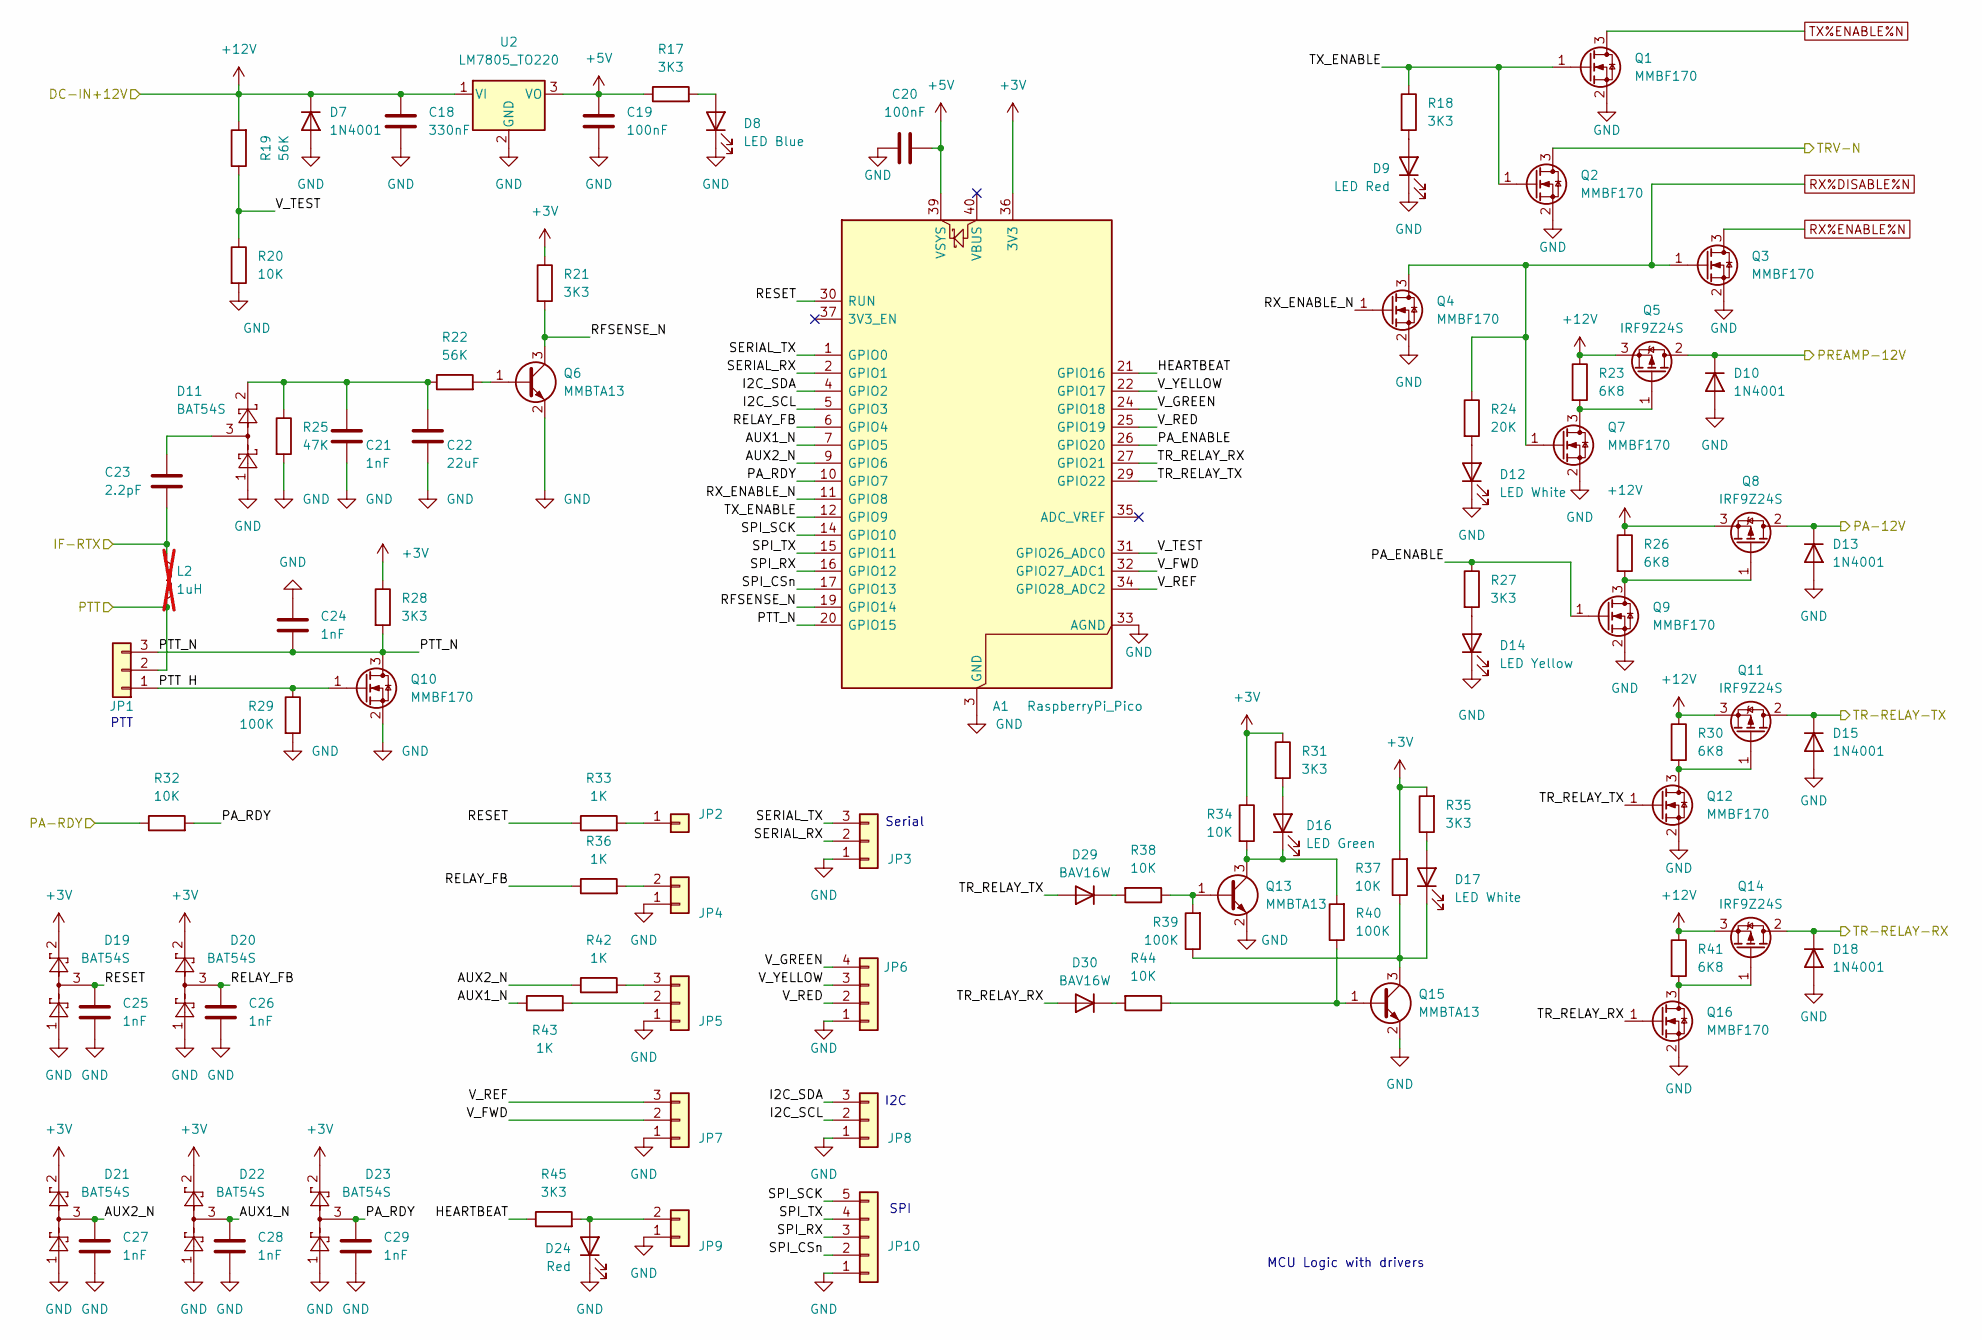
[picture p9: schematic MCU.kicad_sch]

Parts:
A1: RaspberryPi_Pico; RaspberryPi_Pico_Common_THT
C18: 330nF; C_0805_2012Metric_Pad1.18x1.45mm_HandSolder
C19, C20: 100nF; C_0805_2012Metric_Pad1.18x1.45mm_HandSolder
C21, C24, C25, C26, C27, C28, C29: 1nF; C_0805_2012Metric_Pad1.18x1.45mm_HandSolder
C22: 22uF; C_0805_2012Metric_Pad1.18x1.45mm_HandSolder
C23: 2.2pF; C_0805_2012Metric_Pad1.18x1.45mm_HandSolder
D7, D10, D13, D15, D18: 1N4001; D_SMA; LCSC C2456
D8: LED Blue; LED_0805_2012Metric_Pad1.15x1.40mm_HandSolder
D9: LED Red; LED_0805_2012Metric_Pad1.15x1.40mm_HandSolder
D11, D19, D20, D21, D22, D23: BAT54S; SOT-23; LCSC C8592
D12, D17: LED White; LED_0805_2012Metric_Pad1.15x1.40mm_HandSolder
D14: LED Yellow; LED_0805_2012Metric_Pad1.15x1.40mm_HandSolder
D16: LED Green; LED_0805_2012Metric_Pad1.15x1.40mm_HandSolder
D24: Red; LED_0805_2012Metric_Pad1.15x1.40mm_HandSolder
D29, D30: BAV16W; D_SOD-323_HandSoldering
JP1, JP3, JP5, JP7, JP8: Conn_01x03; PinHeader_1x03_P2.54mm_Vertical
JP2: Conn_01x01; PinHeader_1x01_P2.54mm_Vertical
JP4, JP9: Conn_01x02; PinHeader_1x02_P2.54mm_Vertical
JP6: Conn_01x04; PinHeader_1x04_P2.54mm_Vertical
JP10: Conn_01x05; PinHeader_1x05_P2.54mm_Vertical
L2: 1uH; L_1008_2520Metric_Pad1.43x2.20mm_HandSolder; not fitted
Q1, Q2, Q3, Q4, Q7, Q9, Q10, Q12, Q16: MMBF170; SOT-23; LCSC C130879
Q5, Q8, Q11, Q14: IRF9Z24S; TO-220-3_Vertical; LCSC C2576
Q6, Q13, Q15: MMBTA13; SOT-23; LCSC C8520
R17, R18, R21, R27, R28, R31, R35, R45: 3K3; R_0805_2012Metric_Pad1.20x1.40mm_HandSolder
R19, R22: 56K; R_0805_2012Metric_Pad1.20x1.40mm_HandSolder
R20, R32, R34, R37, R38, R44: 10K; R_0805_2012Metric_Pad1.20x1.40mm_HandSolder
R23, R26, R30, R41: 6K8; R_0805_2012Metric_Pad1.20x1.40mm_HandSolder
R24: 20K; R_0805_2012Metric_Pad1.20x1.40mm_HandSolder
R25: 47K; R_0805_2012Metric_Pad1.20x1.40mm_HandSolder
R29, R39, R40: 100K; R_0805_2012Metric_Pad1.20x1.40mm_HandSolder
R33, R36, R42, R43: 1K; R_0805_2012Metric_Pad1.20x1.40mm_HandSolder
U2: LM7805_TO220; TO-220-3_Vertical

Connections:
+3V: A1.36 (3V3), D19.2 (K), D20.2 (K), D21.2 (K), D22.2 (K), D23.2 (K), R21.1, R28.1, R31.1, R34.1, R35.2, R37.2
+5V: A1.39 (VSYS), C19.2, C20.1, R17.1, U2.3 (VO); also elsewhere on the board
+12V: C18.2, D7.1 (K), Q5.3 (S), Q8.3 (S), Q11.3 (S), Q14.3 (S), R19.2, R23.1, R26.1, R30.1, R41.1, U2.1 (VI); also elsewhere on the board
/IF-RTX: C23.1, L2.1; also elsewhere on the board
/MCU Logic/AUX1_N: A1.7 (GPIO5), C28.1, D22.3 (COM), R43.1
/MCU Logic/AUX2_N: A1.9 (GPIO6), C27.1, D21.3 (COM), R42.1
/MCU Logic/HEARTBEAT: A1.21 (GPIO16), R45.1
/MCU Logic/I2C_SCL: A1.5 (GPIO3), JP8.2
/MCU Logic/I2C_SDA: A1.4 (GPIO2), JP8.3
/MCU Logic/PA-12V: D13.1 (K), Q8.2 (D); also elsewhere on the board
/MCU Logic/PA-RDY: R32.1; also elsewhere on the board
/MCU Logic/PA_ENABLE: A1.26 (GPIO20), Q9.1 (G), R27.1
/MCU Logic/PA_RDY: A1.10 (GPIO7), C29.1, D23.3 (COM), R32.2
/MCU Logic/PREAMP-12V: D10.1 (K), Q5.2 (D); also elsewhere on the board
/MCU Logic/PTT: JP1.2, L2.2; also elsewhere on the board
/MCU Logic/PTT H: JP1.1, Q10.1 (G), R29.1
/MCU Logic/PTT_N: A1.20 (GPIO15), C24.2, JP1.3, Q10.3 (D), R28.2
/MCU Logic/RELAY_FB: A1.6 (GPIO4), C26.1, D20.3 (COM), R36.1
/MCU Logic/RESET: A1.30 (RUN), C25.1, D19.3 (COM), R33.1
/MCU Logic/RFSENSE_N: A1.19 (GPIO14), Q6.3 (C), R21.2
/MCU Logic/RX_ENABLE_N: A1.11 (GPIO8), Q4.1 (G)
/MCU Logic/SERIAL_RX: A1.2 (GPIO1), JP3.2
/MCU Logic/SERIAL_TX: A1.1 (GPIO0), JP3.3
/MCU Logic/SPI_CSn: A1.17 (GPIO13), JP10.2
/MCU Logic/SPI_RX: A1.16 (GPIO12), JP10.3
/MCU Logic/SPI_SCK: A1.14 (GPIO10), JP10.5
/MCU Logic/SPI_TX: A1.15 (GPIO11), JP10.4
/MCU Logic/TR-RELAY-RX: D18.1 (K), Q14.2 (D); also elsewhere on the board
/MCU Logic/TR-RELAY-TX: D15.1 (K), Q11.2 (D); also elsewhere on the board
/MCU Logic/TRV-N: Q2.3 (D); also elsewhere on the board
/MCU Logic/TR_RELAY_RX: A1.27 (GPIO21), D30.2 (A), Q16.1 (G)
/MCU Logic/TR_RELAY_TX: A1.29 (GPIO22), D29.2 (A), Q12.1 (G)
/MCU Logic/TX_ENABLE: A1.12 (GPIO9), Q1.1 (G), Q2.1 (G), R18.1
/MCU Logic/V_FWD: A1.32 (GPIO27_ADC1), JP7.2
/MCU Logic/V_GREEN: A1.24 (GPIO18), JP6.4
/MCU Logic/V_RED: A1.25 (GPIO19), JP6.2
/MCU Logic/V_REF: A1.34 (GPIO28_ADC2), JP7.3
/MCU Logic/V_TEST: A1.31 (GPIO26_ADC0), R19.1, R20.1
/MCU Logic/V_YELLOW: A1.22 (GPIO17), JP6.3
GND: A1.3 (GND), A1.8 (GND), A1.13 (GND), A1.18 (GND), A1.23 (GND), A1.28 (GND), A1.33 (AGND), A1.38 (GND), C18.1, C19.1, C20.2, C21.1, C22.1, C24.1, C25.2, C26.2, C27.2, C28.2, C29.2, D7.2 (A), D8.1 (K), D9.1 (K), D10.2 (A), D11.1 (A), D12.1 (K), D13.2 (A), D14.1 (K), D15.2 (A), D18.2 (A), D19.1 (A), D20.1 (A), D21.1 (A), D22.1 (A), D23.1 (A), D24.1 (K), JP3.1, JP4.1, JP5.1, JP6.1, JP7.1, JP8.1, JP9.1, JP10.1, Q1.2 (S), Q2.2 (S), Q3.2 (S), Q4.2 (S), Q6.2 (E), Q7.2 (S), Q9.2 (S), Q10.2 (S), Q12.2 (S), Q13.2 (E), Q15.2 (E), Q16.2 (S), R20.2, R25.2, R29.2, U2.2 (GND); also elsewhere on the board
unnamed: D8.2 (A), R17.2
unnamed: D9.2 (A), R18.2
unnamed: C23.2, D11.3 (COM)
unnamed: C21.2, C22.2, D11.2 (K), R22.1, R25.1
unnamed: D12.2 (A), R24.2
unnamed: D14.2 (A), R27.2
unnamed: D16.2 (A), R31.2
unnamed: D16.1 (K), Q13.3 (C), R34.2, R40.2
unnamed: D17.2 (A), R35.1
unnamed: D17.1 (K), Q15.3 (C), R37.1, R39.1
unnamed: D24.2 (A), JP9.2, R45.2
unnamed: D29.1 (K), R38.2
unnamed: D30.1 (K), R44.2
unnamed: JP2.1, R33.2
unnamed: JP4.2, R36.2
unnamed: JP5.2, R43.2
unnamed: JP5.3, R42.2
unnamed: Q5.1 (G), Q7.3 (D), R23.2
unnamed: Q6.1 (B), R22.2
unnamed: Q8.1 (G), Q9.3 (D), R26.2
unnamed: Q11.1 (G), Q12.3 (D), R30.2
unnamed: Q13.1 (B), R38.1, R39.2
unnamed: Q14.1 (G), Q16.3 (D), R41.2
unnamed: Q15.1 (B), R40.1, R44.1
RX%DISABLE%N: Q3.1 (G), Q4.3 (D), Q7.1 (G), R24.1; also elsewhere on the board
RX%ENABLE%N: Q3.3 (D); also elsewhere on the board
TX%ENABLE%N: Q1.3 (D); also elsewhere on the board

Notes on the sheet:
Serial
I2C
SPI
MCU Logic with drivers
PTT

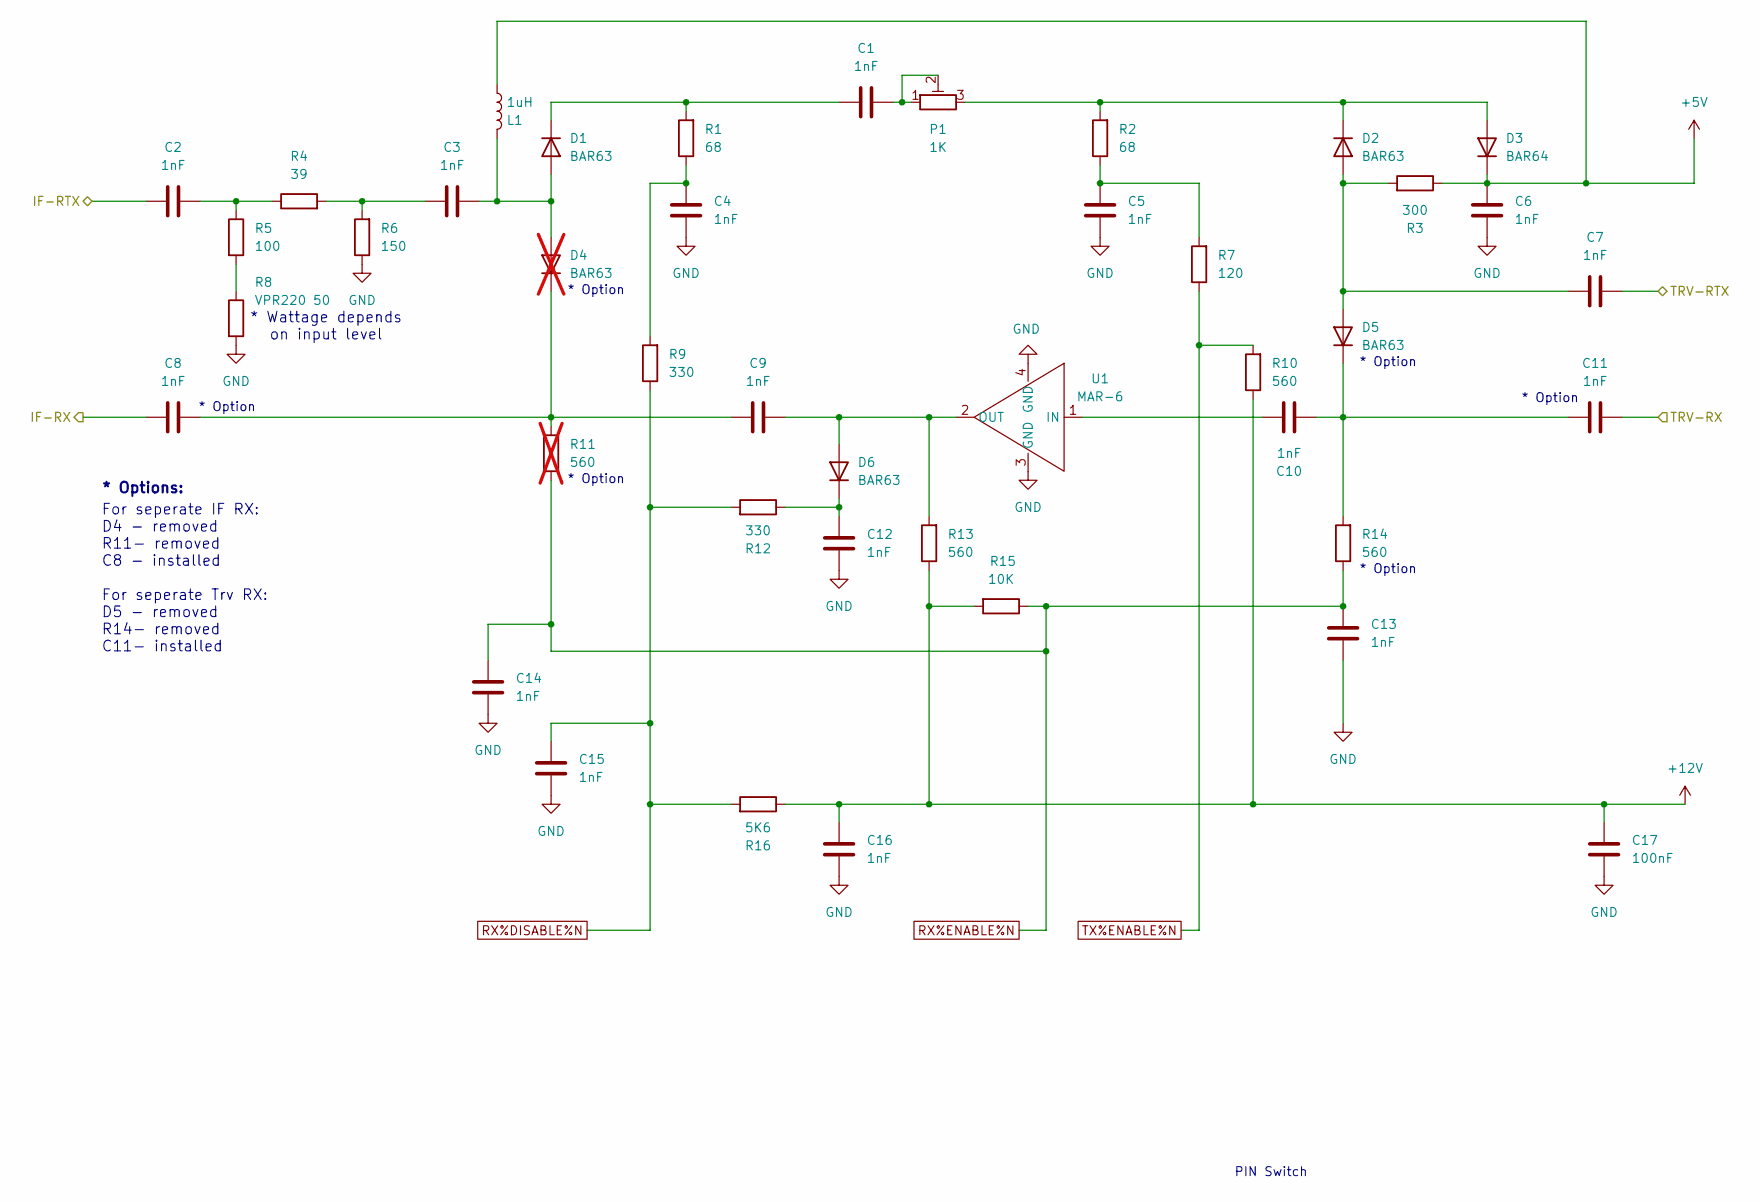
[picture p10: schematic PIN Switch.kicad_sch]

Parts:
C1, C2, C3, C4, C5, C6, C7, C8, C9, C10, C11, C12, C13, C14, C15, C16: 1nF; C_0805_2012Metric_Pad1.18x1.45mm_HandSolder
C17: 100nF; C_0805_2012Metric_Pad1.18x1.45mm_HandSolder
D1, D2, D5, D6: BAR63; D_SOD-323_HandSoldering
D3: BAR64; D_SOD-323_HandSoldering
D4: BAR63; D_SOD-323_HandSoldering; not fitted
L1: 1uH; L_1008_2520Metric_Pad1.43x2.20mm_HandSolder
P1: 1K; Potentiometer_Bourns_3314G_Vertical; LCSC C780221
R1, R2: 68; R_0805_2012Metric_Pad1.20x1.40mm_HandSolder
R3: 300; R_0805_2012Metric_Pad1.20x1.40mm_HandSolder
R4: 39; R_0805_2012Metric_Pad1.20x1.40mm_HandSolder
R5: 100; R_0805_2012Metric_Pad1.20x1.40mm_HandSolder
R6: 150; R_0805_2012Metric_Pad1.20x1.40mm_HandSolder
R7: 120; R_0805_2012Metric_Pad1.20x1.40mm_HandSolder
R8: VPR220 50; TO-220-2_Vertical Resistor
R9, R12: 330; R_0805_2012Metric_Pad1.20x1.40mm_HandSolder
R10, R13, R14: 560; R_0805_2012Metric_Pad1.20x1.40mm_HandSolder
R11: 560; R_0805_2012Metric_Pad1.20x1.40mm_HandSolder; not fitted
R15: 10K; R_0805_2012Metric_Pad1.20x1.40mm_HandSolder
R16: 5K6; R_0805_2012Metric_Pad1.20x1.40mm_HandSolder
U1: MAR-6; MSA_1

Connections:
+5V: C6.2, D3.1 (K), L1.2, R3.1; also elsewhere on the board
+12V: C16.2, C17.2, R10.1, R13.1, R15.2, R16.1; also elsewhere on the board
/IF-RTX: C2.1; also elsewhere on the board
/IF-RX: C8.1; also elsewhere on the board
/TRV-RTX: C7.2; also elsewhere on the board
/TRV-RX: C11.2; also elsewhere on the board
GND: C4.1, C5.1, C6.1, C12.1, C13.1, C14.1, C15.1, C16.1, C17.1, R6.1, R8.2, U1.3 (GND), U1.4 (GND); also elsewhere on the board
unnamed: C1.2, P1.1, P1.2
unnamed: C2.2, R4.1, R5.1
unnamed: C3.1, R4.2, R6.2
unnamed: C4.2, R1.1, R9.2
unnamed: C5.2, R2.1, R7.2
unnamed: C3.2, D1.2 (A), D4.2 (A), L1.1
unnamed: C1.1, D1.1 (K), R1.2
unnamed: C7.1, D2.2 (A), D5.2 (A), R3.2
unnamed: D2.1 (K), D3.2 (A), P1.3, R2.2
unnamed: C8.2, C9.1, D4.1 (K), R11.2
unnamed: C10.2, C11.1, D5.1 (K), R14.2
unnamed: C9.2, D6.2 (A), R13.2, U1.2 (OUT)
unnamed: C12.2, D6.1 (K), R12.1
unnamed: R5.2, R8.1
unnamed: C10.1, U1.1 (IN)
RX%DISABLE%N: C15.2, R9.1, R12.2, R16.2; also elsewhere on the board
RX%ENABLE%N: C13.2, C14.2, R11.1, R14.1, R15.1; also elsewhere on the board
TX%ENABLE%N: R7.1, R10.2; also elsewhere on the board

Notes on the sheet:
* Option
* Wattage depends on input level
For seperate IF RX: D4 - removed R11- removed C8 - installed For seperate Trv RX: D5 - removed R14- removed C11- installed
PIN Switch
* Options:

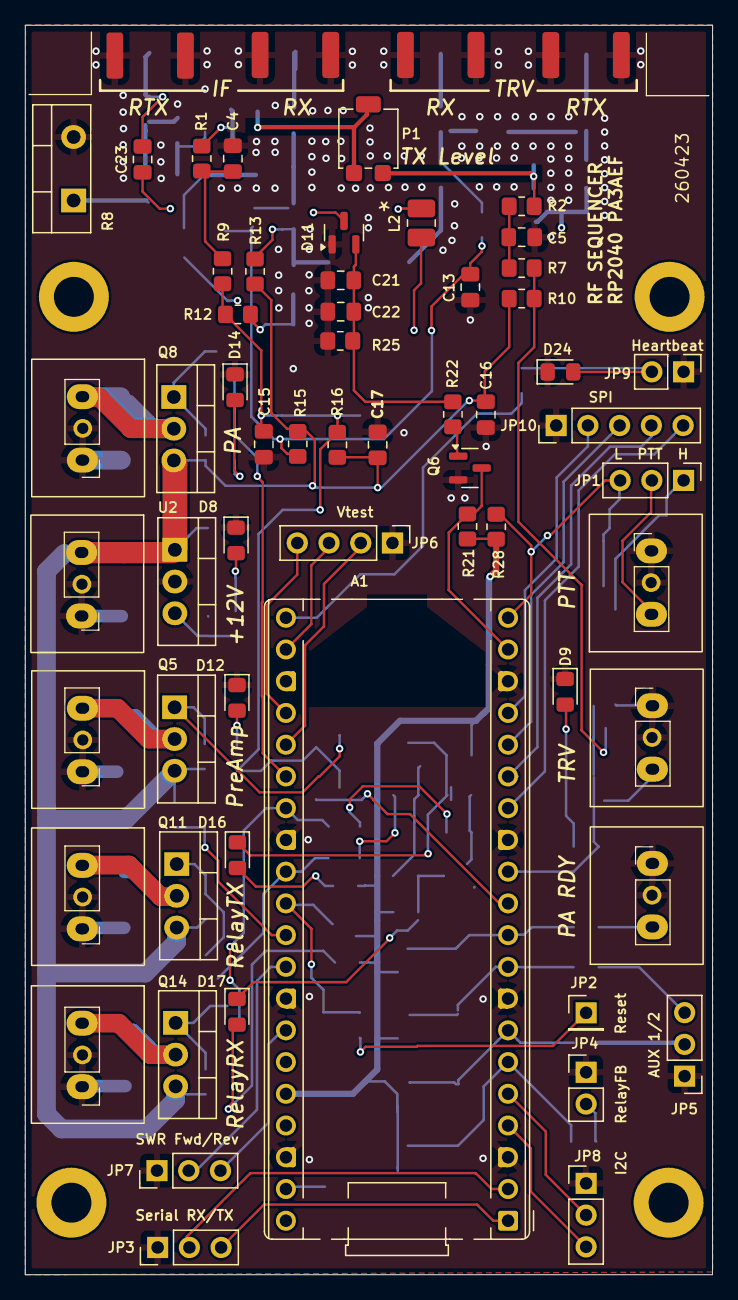
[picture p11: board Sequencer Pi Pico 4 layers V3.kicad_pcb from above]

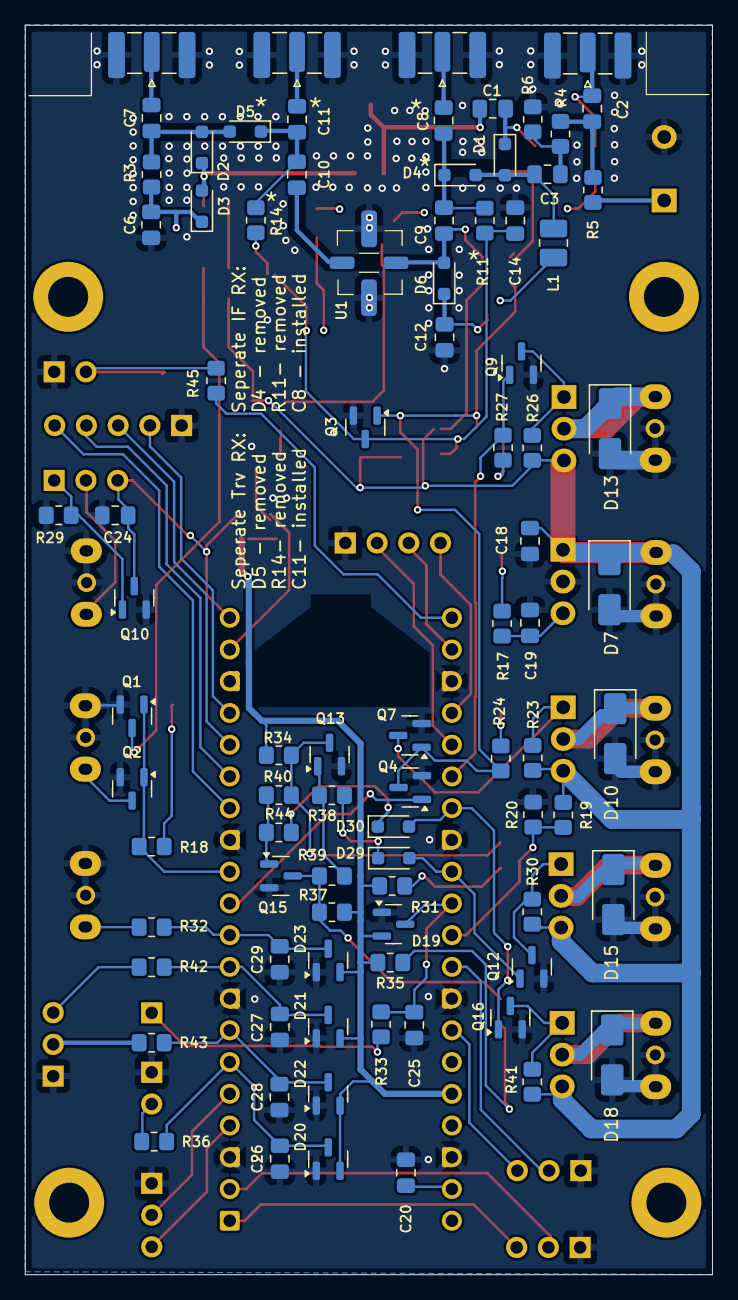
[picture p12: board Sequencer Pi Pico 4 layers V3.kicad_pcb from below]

Board: 4 copper layers, 55.0 x 100.0 mm, 148 parts (86 on the bottom side), 85 nets.

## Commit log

2026-04-08 Added changelog and relay architecture
2026-04-11 Added new relay topology (latching relays etc.)
2026-04-11 New files for PCB
    [MCU.kicad_sch, PIN Switch.kicad_sch, Sequencer Pi Pico 4 layers V3.kicad_pcb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]
2026-04-12 modified: docs/architecture/integration-examples.md modified: docs/firmware/README.md modified: docs/firmware/adc.md modified: docs/firmware/statemachine.md modified: hardware/README.md
2026-04-12 Firmware V1.2 for V3 board
2026-04-23 Fixed circuit for latched relays
    [MCU.kicad_sch, Sequencer Pi Pico 4 layers V3.kicad_pcb, bom.csv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]
2026-04-25 New firmware matching latched relays
